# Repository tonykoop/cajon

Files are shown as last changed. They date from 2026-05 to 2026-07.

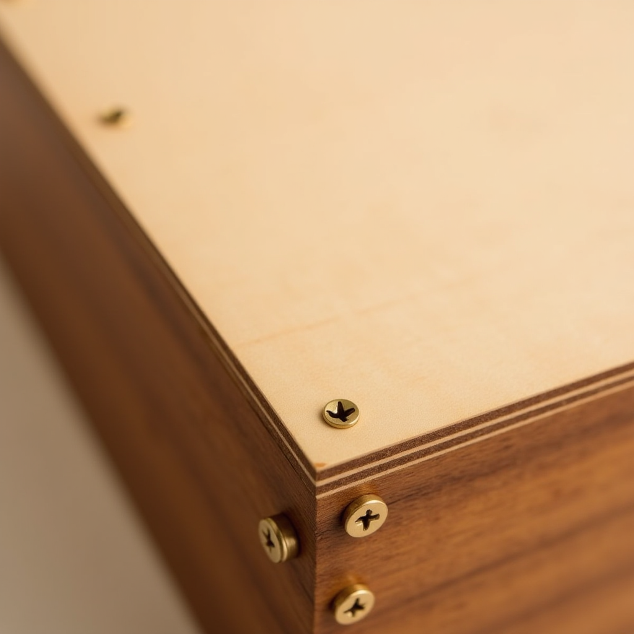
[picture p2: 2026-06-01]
images/macro/tapa-slap-zone.png

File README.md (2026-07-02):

# Cajón — Family Design Packet

**Status:** L2 V5 build-packet candidate — pre-build (not a measured or production-ready release yet; see "Current status" below).

**A parametric three-member box-drum family.** The Peruvian / flamenco cajón as a coordinated set of three sizes (Compact / Standard / Bass) in four interchangeable manufacturing variants, with an optional snare lineage.

Part of the [tonykoop/instrument-maker](https://github.com/tonykoop/instrument-maker) catalogue. Heifer Zephyr Instruments — Tony Koop.

---

## What this is

A complete parametric design packet for a coordinated three-member cajón family. The same design sheet drives all three sizes with a shared geometric law; the same shell can be realized through any of four joinery paths and either of three snare options.

| Member | Outer (H × W × D) | Sound hole | Predicted f_H | Voice |
|---|---|---|---|---|
| Compact (CJ-C)| 15 × 11 × 11 in | 4.0 in Ø | ≈ 107 Hz | bright G♯2/A2 |
| **Standard (CJ-S)** ⭐ | 18 × 12 × 12 in | 4.5 in Ø | ≈ 96 Hz | balanced G2 — first prototype |
| Bass (CJ-B) | 22 × 14 × 14 in | 5.0 in Ø | ≈ 77 Hz | deep D♯2/E2 |

| ID  | Joint | Method | Notes |
|-----|---|---|---|
| V1 ⭐ | Finger / box joint | Table saw + jig OR CNC parametric | First-prototype default |
| V2  | Half-blind dovetail| CNC | Showpiece, harder fixturing |
| V3  | Rabbet | Table saw or router | Quick commercial baseline |
| V4  | Miter + spline | Table saw + spline jig | Spline visual ties to inlay |

| Snare  | Lineage | Voice |
|---|---|---|
| A | Peruvian  | dry, woody, deep "thump" |
| B ⭐ | Flamenco  | bright, snappy slap; modern default |
| C | Studio | thicker buzz from snare-drum wires |

The packet ships acoustic physics, parametric geometry, BOM &middot; sourcing &middot; cut-list &middot; validation, dimensioned drawings, an assembly manual covering all four variants, a red-team risks log, a Wolfram starter notebook, a capstone slide deck, a printable shop packet, and a public build-log site.

## Current authority status

Current status: **pre-build V5 build-packet candidate**. The packet has a
design table, OpenSCAD master, SVG review drawings, CNC/jig notes, print packet,
capstone deck, and explorer, but it is not a measured or production-ready
release yet.

**Blender render scaffolding in place** (Refs #4): `cad/mcp-session-log.md`,
`visual-output-register.csv` render rows, and `images/render-brief.md` are
committed. Actual PNG renders remain `pending_measurement` until a Blender
MCP session runs via Claude Desktop and updates the session log.

Fabrication authority is limited to the named design table, OpenSCAD source,
fixture templates, and reviewed drawing set listed in
`visual-output-register.csv`. Snare response, panel-thickness behavior, joinery
strength, and strike-response claims remain predictions until the Standard
`CJ-S` prototype is built and `validation.csv` contains measured rows.

---

## Governing physics

The cajón's bass voice is the coupling of two systems within a few semitones of each other:

- **Front-plate (1,1) clamped-rectangular bending mode** — the 3 mm Baltic-birch tapa, clamped on all four edges by perimeter screws every 3″, vibrating in a single hump when struck centre.
- **Helmholtz cavity** — the closed walnut box with a 4.5″ back-port hole.

Standard prediction: plate (1,1) ≈ **84 Hz**; cavity ≈ **96 Hz**; perceived bass is the coupled mode of both. Strike centre → bass voice. Strike upper corner → slap zone bends and excites high modes + the snare.

```
f_H = (c / 2π) · √( A / (V · L_eff) )
       L_eff = t_back + 1.7 · (d_hole / 2)
```

The original `cajon-design-table.xlsx` formula used `L_eff = t_back` — missing the 1.7·r end correction. That under-predicted L by ~5–10× and over-predicted f_H by ~3×. Risk **A2** in `risks.md` tracks the correction; `design.md` uses the corrected expression; `cajon-design-table.xlsx` formula update is queued for v2.

For the full derivation, family scaling law, and assumptions, see [`design.md`](design.md).

---

## First prototype

> Build the Standard (CJ-S) in V1 finger-joint with snare option B. Standard is the family's tonal centre; Compact and Bass scale geometrically once Standard's measured tuning lands.

- Estimated material cost: **~$205** (one Standard prototype)
- Estimated build time: **~30 hours over 4 days** with CNC for inlay + joinery
- Default body species: Black walnut · CNC-inlaid sides with maple + yellowheart accents

---

## File map

| File / folder | Purpose |
|---|---|
| [`design.md`](design.md) | Governing physics, family scaling, critical dims, open assumptions |
| [`family-spec.csv`](family-spec.csv) | Three-member sizing law for Compact / Standard / Bass |
| [`cajon-design-table.xlsx`](cajon-design-table.xlsx) | Artisan-style reference workbook (in repo) |
| [`bom.csv`](bom.csv) | Bill of materials, by variant |
| [`sourcing.csv`](sourcing.csv) | Suppliers, lead times, price-volatility flags |
| [`cut-list.csv`](cut-list.csv) | Operation-by-operation cut data |
| [`validation.csv`](validation.csv) | Predicted vs measured tuning + acceptance bands |
| [`validation-report.md`](validation-report.md) | Pre-build validation status, gates, and release checklist |
| [`assembly-manual.md`](assembly-manual.md) | Phase-by-phase build (10 phases × 4 variants × 3 snare options) |
| [`supplier-rfq.md`](supplier-rfq.md) | Q2 2026 batch sourcing summary for prospective suppliers |
| [`drawing-brief.md`](drawing-brief.md) | List of required drawings + conventions |
| [`visual-bom-brief.md`](visual-bom-brief.md) | Visual-BOM photo brief |
| [`photo-shotlist.md`](photo-shotlist.md) | In-shop process photo list |
| [`resources.md`](resources.md) | Provenance, assumptions, and supplier verification notes |
| [`jig-decision.md`](jig-decision.md) | Fixture choices for square assembly, drilling, and repeatability |
| [`risks.md`](risks.md) | Red-team failure-mode walk (17 risks, 5 categories) |
| [`visual-output-register.csv`](visual-output-register.csv) | Visual/CAD authority chain for drawings, templates, generated previews, and image placeholders |
| [`wolfram-starter.wl`](wolfram-starter.wl) | Wolfram package: plate, Helmholtz, two-zone synthesis |
| [`capstone-deck.md`](capstone-deck.md) | Markdown capstone companion for validator and review |
| [`capstone-manifest.json`](capstone-manifest.json) | Capstone file map and public-release concerns |
| [`print-packet.md`](print-packet.md) | Printable shop packet in Markdown |
| [`print-packet.html`](print-packet.html) | Browser-printable shop packet |
| [`drawings/`](drawings/) | Dimensioned SVG drawings (sheets 1–8) |
| [`cad/`](cad/) | OpenSCAD parametric master (`cajon-master.scad`) |
| [`evolution/`](evolution/) | StudioPipeline Stage-0 intake (design intent, master manifest, revisions) |
| [`cnc/`](cnc/) | CNC bit + feed strategies for finger-joint, inlay, sound hole |
| [`jigs/`](jigs/) | Fixture drawings for square assembly and tapa screw layout |
| [`images/`](images/) | Concept/support image placeholders; future real build photos only after prototype evidence exists |
| [`data/`](data/) | Measurement-log landing zone for first-build spectral, load, and fit data |
| [`site/index.html`](site/index.html) | Public build-log site |
| [`scripts/`](scripts/) | Generators for xlsx, pptx, pdf binaries |
| [`BUILD.md`](BUILD.md) | How to regenerate the binary deliverables |
| [`LICENSE`](LICENSE) | CC BY 4.0 |

Generated binaries (run `python scripts/build_all.py`):

- `Cajon-Family-Design.xlsx` — parametric workbook ingesting the CSVs
- `Cajon-Family-Capstone.pptx` — capstone slide deck
- `Cajon-Family-Print-Packet.pdf` — printable shop packet
- `capstone-deck.pptx` and `print-packet.pdf` — validator-compatible root-mode aliases

---

## What's parametric vs measured

| Parametric (formula-driven, edit the workbook to change) | Measured (TBD on first prototype) |
|---|---|
| Helmholtz frequency f_H per member | Actual f_H of the assembled cavity |
| Plate (1,1) mode estimate per member | Actual plate (1,1) of mounted tapa |
| Internal cavity volume | Slap-vs-centre spectral delta |
| Sound-hole area + L_eff | Snare-buzz onset velocity (subjective) |
| Family table dimensions | Sustain T60 of the bass voice |
| Joint / bit / feed parameters | Tapa screw-torque uniformity |

---

## Status &amp; roadmap

- **Design v1 — shipped as pre-build V5 candidate.** Governing physics, family scaling, BOM/sourcing/cut-list/validation, drawings, CAD master, CNC notes, jigs, risks, Wolfram starter, build-log site, build scripts, explorer, and authority register.
- **First prototype build — pending.** Standard (CJ-S), V1 finger-joint, snare option B.
- **Tuning calibration — pending first measurement.** Once recorded, the family scaling law gets cross-checked against the data per the empirical-learning loop in the parent `instrument-maker` skill.
- **Drawings v2 — queued.** Current sheets 01–08 are public-review SVGs; next pass should replace simplified sheets with CAD-exported dimension drawings after the first build review.
- **Workbook formula revision — queued.** Replace `L = t_back` with `L_eff = t_back + 1.7·r` in `cajon-design-table.xlsx`.

## Review Evidence

- `git diff --check` is expected to pass for the packet branch.
- `python3 /home/tony/.codex/skills/instrument-maker-v4/scripts/validate_packet.py . --mode root`
  is the root-mode gate before merge review.
- This packet is a pre-build V5 candidate: design, sourcing, cut list,
  drawings, CNC notes, jigs, risks, validation plan, print packet, capstone,
  explorer, and visual authority register are present for human review.
- Empirical/build gates remain deferred until the Standard CJ-S prototype is
  assembled, measured, and logged in `validation.csv`.

---

## License

[CC BY 4.0](LICENSE) — see LICENSE for details.

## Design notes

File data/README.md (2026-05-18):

# Cajon Measurement Data

This folder is the landing zone for measured CJ-S prototype data.

Do not promote the packet beyond pre-build V5 candidate status until measured
rows exist in `../validation.csv` and source files are added here for the
critical gates:

- panel thickness after milling and after inlay routing;
- finger-joint scrap-fit and glue-line checks;
- shell diagonal/squareness and seat-load results;
- centre-strike and corner-strike audio captures or spectrum summaries;
- snare-onset notes for option B guitar-string snare;
- finish and tapa screw-torque observations.

Suggested file names:

- `cj-s-panel-thickness.csv`
- `cj-s-shell-squareness.csv`
- `cj-s-strike-spectrum.csv`
- `cj-s-snare-onset.md`

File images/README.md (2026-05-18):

# Cajon Images

This folder is reserved for real CJ-S build photos, validated renders, and
future concept/support imagery.

Generated images and site previews are concept/support only. They must not be
used to infer panel thickness, snare contact geometry, screw positions, joinery
tolerances, or CNC toolpaths. Record any accepted visual artifact in
`../visual-output-register.csv` before referencing it from the README, explorer,
site, print packet, or capstone deck.

Recommended future evidence:

- `cj-s-hero.jpg` after the first real prototype is built.
- `snare-contact-closeup.jpg` after snare preload is set.
- `tapa-screw-pattern.jpg` after the tapa is mounted.
- `validation-setup.jpg` showing tap-test or spectrum capture setup.

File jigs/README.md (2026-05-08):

# Cajon Jigs

The cajon looks like a cabinet until the tapa goes on. These jigs keep it an instrument.

## Required for CJ-S first prototype

1. **Square assembly fixture** - flat baseboard with fixed 90-degree fences and movable clamp blocks. Use during dry fit and glue-up.
2. **Tapa screw template** - hardboard or acrylic drill template indexed from the bottom outside edge and centerline. This protects the screw spacing and the unscrewed slap-zone margin.
3. **Back-panel template** - sound-hole center, tuner holes, and snare mount pilot layout. This can be combined with the tapa template if made from clear acrylic.

## Optional variant jigs

- **Finger-joint sled** for a table-saw V1 build.
- **Spline sled** for V4 miter+spline corners.
- **CNC dovetail fixture** for V2 half-blind dovetails.

## Build order

Make the square assembly fixture and screw template before cutting final tapa stock. The templates should be tested on scrap with the exact screws and tuner hardware from `bom.csv`.

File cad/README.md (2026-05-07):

# CAD — Cajón Family

This folder is the home for SolidWorks parametric models, OpenSCAD masters, and CAD-export geometry that drives the manufacturing files in `cnc/` and the dimensioned drawings in `drawings/`.

## Status

The cajón is a six-panel rectilinear box, simpler than a turned-shell instrument like the conga or udu. CAD complexity sits in the joinery (finger / dovetail / spline) and the inlay zone, not in the body geometry. As of v1:

- **`cajon-master.scad`** — OpenSCAD parametric master for the box body, sound hole, and finger-joint corners. Edit the parameters at the top, render, and export STL/DXF.
- **SolidWorks model** — *queued for v2*. Standard SW workflow per `instrument-maker-v4/references/solidworks-integration.md`: MasterLayout part + design table linked to `cajon-design-table.xlsx`. The OpenSCAD model is sufficient for v1 cut-list verification.

## Workflow

1. Edit the OpenSCAD master parameters to match the family member you want (Compact / Standard / Bass).
2. Render in OpenSCAD; export DXF (top view) for laser-cutting flat panels OR STL (full body) for visualization.
3. Cross-check OpenSCAD geometry against `cajon-design-table.xlsx` outputs; numbers must agree.

## Files

| File | Purpose |
|---|---|
| `cajon-master.scad` | OpenSCAD parametric body — edit + render |
| (planned) `cajon-master.sldprt` | SolidWorks part with design table |
| (planned) `cajon-assembly.sldasm` | SolidWorks assembly: 6 panels + glue blocks |
| (planned) `cajon-drawing.slddrw` | SolidWorks drawing → exports the SVGs in `../drawings/` |

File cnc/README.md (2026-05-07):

# CNC — Cajón Family

CNC strategy notes for the three operations on the cajón that benefit from CNC vs hand-tool execution: **(1)** finger-joint corners, **(2)** inlay pockets and inserts, **(3)** the back-panel sound hole.

The cajón is otherwise table-saw / router / hand-tool friendly. There is no complex profile-turning or coupling like the conga or fujara — the box is rectilinear.

## Machine + tooling assumptions

- Router: ShopBot Desktop or equivalent (24″ × 36″ work envelope minimum)
- Spindle: 2.2 kW, variable 6,000–24,000 RPM
- Bits used:
  - **TBN-12.4** — Amana 45739, 12.4° tapered ball-nose, 1/4″ shank — for inlay pocket + insert
  - **SF-1/2** — Amana 46176, 1/2″ straight-flute spiral, 1/4″ shank — for finger joint
  - **DT-14** — Amana 45813, 14° dovetail, 1/2″ — for V2 dovetail (optional)
  - **HSAW-4.5** — 4.5″ hole-saw (alternative to CNC pocket for sound hole)
- Vacuum hold-down preferred for inlay panels; T-track clamps acceptable for joinery.

## Operation 1 — Finger-joint corners (V1)

The 1/2″ spiral bit cuts 0.375″-wide finger pockets. Standard pin spacing is 0.375″; for a 12″ panel that's 32 fingers — even number, alternating pins, mating panels offset by one pin width.

```
Bit:        SF-1/2 (1/2" straight-flute spiral)
Feed:       40 IPM
Plunge:     12 IPM
RPM:        16,000
Step-down:  0.25" per pass (max)
Tool path:  pocket toolpath, ramp entry
```

**Critical:** verify kerf and spiral direction with a test cut on scrap. A down-cut spiral leaves a cleaner top edge but loads chips downward; an up-cut clears chips but tear-outs the top edge of walnut. Compromise: compression bit if you have it; up-cut + skim pass at 0.005″ depth as a finish pass otherwise.

The finger pattern is **mirrored on mating panels** — left side of side panel mates with left side of top panel; the pocket on one is the pin on the other. Generate the mating G-code from the same VCarve project, just toggle the layer.

## Operation 2 — Inlay pocket + insert (Broinwood-derived)

This is the high-leverage CNC operation on the cajón. It's the visual signature.

```
Bit:        TBN-12.4 (12.4° tapered ball-nose)
Feed:       30 IPM
Plunge:     10 IPM
RPM:        18,000
Pocket depth:    0.080–0.100" (pocket = negative, in walnut)
Insert depth:    pocket_depth + 0.020" (positive, in maple)
Tool path:  follow-vector for insert; pocket-clearance for pocket
```

The bit's tapered profile creates undercut walls in the pocket and matching tapered shoulders on the insert. As the insert is pressed in, the tapered shoulder seats against the tapered pocket wall — no glue gaps visible from the top once flush-sanded.

**VCarve allowance setting:** start at 0.000″ (factory default). If dry-fit is too tight (insert won't seat with thumb pressure), increase by 0.005″. If dry-fit is loose (rocks in pocket), decrease by 0.005″. *Always test on scrap before committing to the panel.*

**Panel keep-out:** route only within the central 70 % of the panel — keep 1″ clear of every joint edge so the joinery has solid wood.

## Operation 3 — Sound hole

Two acceptable paths:

**A. CNC pocket (preferred)** — cleanest result, no rasping required.
```
Bit:        SF-1/2 (1/2" straight-flute spiral)
Feed:       30 IPM
Plunge:     8 IPM
RPM:        16,000
Step-down:  0.10" per pass
Tool path:  pocket-clearance, spiral-entry, full-through (back panel is 0.5")
```

**B. Hole saw + jigsaw + rasp** — works fine, more cleanup.
- 4.5″ hole saw on drill press, low RPM (~250)
- Or: drill 1/2″ pilot, jigsaw + circle jig
- Rasp + 220 grit deburr both sides

Either way: **deburr both sides 220 grit minimum.** A sharp inside edge on the sound hole creates audible high-frequency hash on slap strokes.

## Operation 4 — Half-blind dovetail (V2 optional)

```
Bit:        DT-14 (1/2" 14° dovetail)
Feed:       25 IPM
Plunge:     8 IPM (carefully — dovetail bits do not plunge well; ramp instead)
RPM:        14,000
Tool path:  Dovetail-specific (use VCarve's half-blind dovetail wizard)
```

Half-blind dovetails on a CNC need a precision fixture — the bit cuts pin and tail in two different orientations, and the panels must register identically. Use a sled fixture or Whiteside-style dovetail jig with CNC-mounted bits if available.

## File outputs (planned, not yet generated)

- `cajon-fingerjoint-side.nc` — G-code for finger-joint side panel pockets
- `cajon-fingerjoint-top.nc` — G-code for top/bottom panel mating fingers
- `cajon-inlay-pocket.nc` — pocket toolpath for inlay pattern (panel-A example)
- `cajon-inlay-insert.nc` — insert toolpath for matching inlay
- `cajon-soundhole.nc` — pocket toolpath for back-panel sound hole

Generate these from VCarve Pro projects pulling geometry from `cajon-master.scad` (export DXF) and the inlay artwork SVGs (Broinwood-style geometric patterns or custom).

## Setup checklist

Before any CNC pass on a real panel:
- [ ] Spoilboard surfaced flat within 0.005″
- [ ] Vacuum or clamps verified (no movement under hand pressure)
- [ ] Bit depth-of-cut and shank engagement checked
- [ ] X/Y/Z zero set to a permanent reference (not the corner of the workpiece)
- [ ] Test cut on identical-thickness scrap at the same fixture position
- [ ] Dust collection on, ear protection on
- [ ] First 10 % of toolpath observed before walking away

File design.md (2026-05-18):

# Cajón Family — Parametric Design Sheet

**Owner:** Tony Koop · Heifer Zephyr Instruments
**Family:** Box drum, six-sided closed box, single thin front plate (tapa), back-port Helmholtz, optional internal snare
**Members:** Compact (CJ-C), Standard (CJ-S, prototype), Bass (CJ-B) — coordinated three-size family
**Manufacturing variants:** four end-to-end paths (V1 finger-joint / V2 dovetail / V3 rabbet / V4 miter+spline) — each with a snare/no-snare option
**Status:** Design v1 — workbook formulas parametric; family tuning predictions populated; first prototype is Standard with finger-joint shell + guitar-string snare; tuning calibration pending first measurement.

---

## Authority boundary

This packet is a pre-build V5 build-packet candidate. The design table,
OpenSCAD master, jig templates, and reviewed SVG sheets are the current planning
authority. They are not a substitute for measured panel stock, CNC test cuts,
seat-load tests, strike-response captures, or snare-onset measurements.

Generated previews, site imagery, visual-BOM layouts, and future concept images
are support artifacts only. The packet records visual and CAD authority in
`visual-output-register.csv`; no image or preview should be used to infer panel
thickness, snare contact geometry, screw positions, joinery tolerances, or CNC
toolpaths.

## 1. Intent

Document the cajón as a portfolio-grade parametric instrument, not as one box. The same design sheet drives three sizes (Compact / Standard / Bass) with a single shared geometric law, and the same shell can be realized through four joinery paths and either lineage of snare:

| Lineage | Snare | Character |
|---|---|---|
| Peruvian  | None (or finger-mute pad) | Dry, woody, deep "thump"; tonal pitch reads cleanly |
| Flamenco  | Guitar strings (adjustable) | Bright, snappy slap on edges; modern default |

A fifth artifact — the existing CNC inlay workflow (Broinwood-derived) — is the visual signature: walnut body with maple/yellowheart inlay panels, with the inlay routed before assembly so the pockets are clamped flat.

The cajón's "secret" is that two simultaneous resonators tune together: the Helmholtz cavity (`f_H`) sits within a few semitones of the tapa (1,1) plate mode, and the player perceives the *coupled* note as the bass voice. Designing the family is therefore a matter of co-tuning those two systems while keeping snare-buzz, slap-zone geometry, and seat-height ergonomics inside their own envelopes.

---

## 2. Family scaling law

The cajón family is a *closed-box, single-thin-plate, back-ported Helmholtz* drum. Two governing modes are co-dominant in the bass voice: the front-plate (1,1) bending mode and the cavity Helmholtz mode. Both must be modeled; the perceived bass pitch is the lower of the two if they are well separated, or a coupled hybrid if they are within ~6 semitones.

### 2.1 Tapa front plate — clamped rectangular plate, (1,1) mode

For an orthotropic plywood plate clamped on all four edges (the cajón seats the tapa under screws every ~3″ around the perimeter; the central span is the active region), the (1,1) bending-mode fundamental is approximated by the isotropic clamped-plate expression:

```
f_plate_(1,1) ≈ (π / 2) · (1/a² + 1/b²) · √( D / (ρ · h) )
```

where `a, b` are the clear span (in metres), `h` is plate thickness, `ρ` is panel density, and `D = E·h³ / (12·(1−ν²))` is flexural rigidity.

For a 3 mm Baltic-birch tapa (`E ≈ 8 GPa`, `ρ ≈ 680 kg/m³`, `ν ≈ 0.30`), this places the (1,1) mode in the 60–110 Hz band over the family — which is exactly where you want it for "thump on the centre, snap on the edge."

### 2.2 Cavity — Helmholtz back-port

For the box cavity coupled to a circular back-port:

```
f_H = (c / 2π) · √( A / (V · L_eff) )
       L_eff = t_back + 1.7 · (d_hole / 2)
```

where `V` is internal volume, `A = π·(d/2)²` is the port area, `t_back` is back-panel thickness, and `1.7·r` is the standard end-correction for a thin-wall flush orifice (both sides counted).

The original spreadsheet (`cajon-design-table.xlsx`) used `L_eff = t_back` only. That under-predicts L by ~5–10× for typical cajón dimensions and over-predicts `f_H` by a factor of ~3. The corrected formula is what the workbook uses now; the historical predictions are flagged in `risks.md` as **A4**.

### 2.3 Family scaling

Volume scales roughly with H·W·D, so `f_H ∝ 1/√V` for a constant port. To keep `f_H` proportional to a target pitch span across the family, the port diameter is also scaled — larger box ⇒ larger port to push `f_H` back up; smaller box ⇒ smaller port. The catalog defaults below split the family into a P1 / P2 / P3 voice each separated by ~3–4 semitones.

| Member | H (in) | W (in) | D (in) | Body t (in) | Back t (in) | Port d (in) | Tapa t (mm) | Predicted f_H (Hz) | Predicted plate (1,1) (Hz) | Tonal voice |
|---|---|---|---|---|---|---|---|---|---|---|
| Compact (CJ-C)| 15 | 11 | 11 | 0.625 | 0.50 | 4.0 | 3 | 107 | 107 | bright A2/G♯2 |
| **Standard (CJ-S) ⭐** | 18 | 12 | 12 | 0.75 | 0.50 | 4.5 | 3 | **96** | **84** | balanced G2 |
| Bass (CJ-B) | 22 | 14 | 14 | 0.75 | 0.50 | 5.0 | 3 | 77 | 60 | deep D♯2/E2 |

All values from the parametric design sheet; the workbook is the source of truth for any update.

The Compact accidentally lands with `f_H ≈ f_plate` — that's the "tightly coupled" regime and produces the punchiest, most pitch-distinct bass in the family. The Bass deliberately separates them by ~5 semitones so the cavity rumble dominates; the plate then acts mainly as the slap voice.

---

## 3. Snare strategy

The cajón has three valid snare paths. The workbook supports all three; the first prototype runs **option B**:

| ID | Snare | Mechanism | Use |
|----|---|---|---|
| A  | None (Peruvian) | bare cavity; finger pad or palm mute on outside if a softer, more melodic voice is wanted | trad / world percussion |
| B  | Guitar-string snare ⭐ | 3–4 wound or plain steel guitar strings clamped on an angled internal block; tension adjustable via guitar tuners | flamenco / modern default |
| C  | Snare-drum wires | a section of standard snare-drum wires mounted on a tension lever; thicker buzz, less articulate | studio / loud genres |

Snare wires sit *behind* the tapa, lightly contacting the inside face. The contact force is the tunable: too light = no buzz; too heavy = chokes the slap and overhangs the bass.

---

## 4. Joinery / construction variants

The shell is a six-sided box. Five of the six faces (top, bottom, two sides, back) are 3/4″ Black Walnut by default; the sixth face is the 3 mm Baltic birch tapa. The four major joinery paths each ship as a manufacturable option:

| ID | Joint | Method | Strength | Visual | Difficulty | Notes |
|----|---|---|---|---|---|---|
| V1 | Finger / box joint ⭐  | table saw + jig OR CNC parametric | ★★★ | ★★★ — contrasting maple fingers possible | medium | First-prototype default; CNC route enables variable-width fingers |
| V2 | Half-blind dovetail | CNC | ★★★ | ★★★ — heirloom | hard | Showpiece path; needs jig fixtures + dust collection |
| V3 | Rabbet | table saw or router | ★★ | ★ — hidden | easy | Commercial baseline; quickest to build |
| V4 | Miter + spline | table saw + spline jig | ★★★ | ★★★ — contrasting splines visible | medium | Clean show-up corners; spline inlay ties to the inlay aesthetic |

V1 (finger joint) is the recommended first prototype: it tolerates ±0.005″ panel error gracefully, the jig is reusable, and the visible joint complements the inlay.

The tolerance claim is a design target, not a measured result. Validate it with
scrap finger-joint samples and the square assembly jig before cutting show
stock.

---

## 5. CNC inlay strategy

The cajón's six flat faces are a perfect canvas for the Broinwood-style ball-nose inlay technique. Critical rule: **route inlay before assembly.** Once the box is glued, you cannot clamp panels flat for routing.

The workflow ships in detail on `cajon-design-table.xlsx` § "CNC Inlay Workflow". Summary:

1. Two paired toolpaths per inlay element: a *pocket* (negative) cut into the body panel and an *insert* (positive) cut from contrasting wood. Both use the same TBN 12.4° tapered-ball-nose bit.
2. Pocket depth 0.080–0.100″; feed 30 IPM at 18,000 RPM in walnut. Test-cut on scrap to dial allowance.
3. The inlay-allowance setting in VCarve Pro controls press-fit. Too tight cracks the insert; too loose leaves a visible gap line.
4. Glue with Titebond III, clamp flat with wax-paper underlay, cure 24 hours, then drum-sand the panel flush before joinery.

Visual layout default for the prototype:
- **Side panels (2):** geometric mandala or Celtic-knot pattern, ~70% of panel area
- **Back panel:** rosette around the sound hole only
- **Top (seat):** subtle border inlay; nothing raised (you sit on it)
- **Tapa:** no inlay (active surface, you hit it; preserve plate uniformity)

---

## 6. Critical dimensions (Standard, V1 finger-joint, snare option B)

These are the numbers that drive cut-list, drawings, and CNC. Anything not here is either derived in the workbook or a non-critical aesthetic choice.

| Feature | Dimension | Tolerance | Source |
|---|---|---|---|
| Outer height | 18.000″ | ±0.020″ | family table |
| Outer width | 12.000″ | ±0.020″ | family table |
| Outer depth | 12.000″ | ±0.020″ | family table |
| Body panel thickness | 0.750″ | ±0.005″ | stock spec |
| Tapa thickness | 0.118″ (3 mm) | +0/−0.005″ | Baltic birch ply spec |
| Back panel thickness | 0.500″ | ±0.005″ | stock spec |
| Sound-hole diameter | 4.500″ | ±0.020″ | family table |
| Sound-hole position | centred L–R, 1/3 H from top on back panel | ±0.10″ | trad practice |
| Tapa screw spacing | every 3″ | ±0.10″ | trad practice |
| Slap-zone unscrewed margin | top 4–5″ of tapa, both upper corners | as drawn | trad practice |
| Internal corner glue blocks | 8× ¾″ triangle, full panel height | hand-fit | rigidity / overtone control |
| Snare angle (option B) | 8–12° off vertical, contact 1″ below top | ±2° | trad practice |
| Rubber-foot height | 0.50″ | ±0.05″ | airflow + bass projection |

Datums for drawings: bottom outside face = primary horizontal datum (Z = 0); back outside face = secondary; centerline of tapa width = vertical reference.

---

## 7. What's parametric vs. what's measured

**Parametric (formula-driven, edit the workbook to change):**
- Helmholtz frequency `f_H` per member
- Plate (1,1) mode estimate per member
- Internal cavity volume
- Sound-hole area and effective neck length
- Family table member dimensions
- Joint / bit / feed parameter recommendations

**Measured (TBD on first prototype, will populate `validation.csv`):**
- Actual `f_H` of the assembled cavity (tap-and-record, expect ±10 Hz from prediction)
- Actual plate (1,1) of the mounted tapa (varies with screw torque and tapa moisture)
- Slap-zone vs centre-strike spectrum delta (`risks.md` E1 acceptance test)
- Snare-buzz onset velocity (subjective; recorded per snare option)
- Sustain T60 of the bass voice
- Actual panel thickness after milling, tapa thickness after finish, and any
  local thinning from CNC inlay pockets
- Finger-joint fit, glue-line closure, diagonal squareness, and seat-load
  behavior

A second-pass design sheet revision happens after the first prototype is measured. The empirical correction (`f_H_predicted` vs `f_H_measured`) gets logged in `validation.csv`, and any cents-error >50 cents triggers a family-table revisit.

---

## 8. Open assumptions

These are explicit so the reviewer knows what is *concept* vs *manufacturable*:

1. **Tapa material is treated as isotropic.** Real Baltic birch ply is mildly orthotropic; the (1,1) prediction is a coarse estimate — expect ±20% from the simple formula. A measured tapa will be the source of truth.
2. **Snare contact pressure is not yet a parameter** in the workbook. It is dialed by ear on the first prototype.
3. **Glue-block contribution to plate clamping is unmodeled.** The 8 internal glue blocks effectively change the plate boundary condition near the corners; we treat the full panel as clamped, which over-stiffens the model slightly.
4. **CNC inlay pocket depth has not been verified to leave structural panel above the pocket.** 0.080″ pocket in 0.625″ stock leaves 0.545″ — comfortably safe — but is recorded as a check in `risks.md` (S2).
5. **Panel material defaulted to Black Walnut** for the visual contrast story; the workbook supports any species but the BOM and cost numbers assume walnut.

---

## 9. First-prototype recommendation

Build the **Standard (CJ-S), V1 finger-joint, snare option B** as the first instrument. Reasons:

- Standard is the family's tonal centre; if its measured tuning lands on prediction, the Compact and Bass scale by simple geometry from there.
- V1 finger-joint is forgiving on stock-prep error and uses the same CNC fixture as future variants.
- Snare option B (guitar strings) is the modern default; the snare can be removed or detensioned to demo "Peruvian style" without rebuilding the box.

Total estimated material cost for prototype: ~$200 (see `bom.csv`). Estimated build time, in-shop, with CNC for joinery and inlay: ~30 hours over 4 days (acclimate / mill / inlay / joinery / glue-up / sand / finish / mount / tune).

---

## 10. References

- `cajon-design-table.xlsx` — workbook source of truth (all formulas live)
- `bom.csv` — bill of materials, all variants
- `sourcing.csv` — suppliers, lead times, price-volatility flags
- `cut-list.csv` — operation-by-operation lumber and stock cuts
- `validation.csv` — predicted vs measured tuning + acceptance bands
- `assembly-manual.md` — phase-by-phase build procedure
- `risks.md` — red-team acoustic / structural / ergonomic / supply / fit-finish failure modes
- `wolfram-starter.wl` — Wolfram package: plate, Helmholtz, two-zone synthesis
- `drawing-brief.md` — list of required drawings + conventions
- `drawings/*.svg` — dimensioned drawings
- `cad/` — SolidWorks placeholders (master layout to follow)
- `cnc/` — CNC inlay and finger-joint cut strategy notes
- `site/index.html` — public build-log site

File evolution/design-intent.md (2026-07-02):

# Design Intent — cajon rev A

- Master CAD: `cad/cajon-master.scad` (sha256: c33970154a3aaa114a9b48958d318e404c76e641e9f412e323f79ac2b02813f1), driven by `Cajon-Family-Design.xlsx` (sha256: d51e6aaaaa010b24bf17f511e03ac4ad37278c9b550844330ec9c4292a9f9eab) and `family-spec.csv`.
- Function: Parametric three-member box-drum family (Compact / Standard / Bass) in four manufacturing variants. A thin plywood front plate (tapa) is struck; its plate (1,1) mode couples with a Helmholtz cavity resonance through a back sound hole to produce bass and slap zones. CJ-S Standard is the first public-review prototype.
- Environment: seated hand-played acoustic box drum; plywood plates move with humidity (tapa stiffness ∝ h³); tapa is screwed (field-replaceable), body panels glued.
- Target qty: 1 (CJ-S Standard prototype first). Deadline: TBD. Budget/unit ceiling: TBD.

## Critical dimensions (carry tolerances)

| Feature | Nominal (CJ-S Standard) | Tolerance | Why critical | Source |
| --- | --- | --- | --- | --- |
| Outer HxWxD | 18.0 x 12.0 x 12.0 in | cut-list gate | seating / cavity volume | family-spec.csv CJ-S |
| Tapa thickness | 3.0 mm BB-grade birch | reject sheets >0.010 in off nominal | plate (1,1) ∝ h^3 → pitch | family-spec.csv / risks SU1 |
| Sound hole diameter | 4.5 in | affects f_H via effective length | Helmholtz tuning | family-spec.csv CJ-S |
| Predicted Helmholtz f_H | ~96 Hz (with 1.7·r end correction) | measure on prototype | bass voice | design.md / risks A2 |
| Predicted plate (1,1) | ~84 Hz | measure on prototype | slap/bass coupling | family-spec.csv CJ-S |
| Body / back thickness | 0.750 / 0.500 in | glue-joint squareness | structure | family-spec.csv CJ-S |

## Incidental (free for DFM)

- Finger-joint vs alternative corner variant, inlay/cosmetic detail, external finish, snare-option lineage (A/B), non-mating surface treatment.

## Must-nots (DFM may never violate)

- Do not use the original `cajon-design-table.xlsx` Helmholtz formula without the `1.7·r` end correction (L_eff = L + 1.7·r) — the uncorrected formula mispredicts f_H badly (risks A2).
- Do not spec non-BB / non-marine-grade ply; layer-adhesion and thickness variance (±8%) shift plate pitch ~15% (risks SU1, A1).
- Do not over-tighten the lower tapa screws — it tenses the slap zone at rest (risks mitigation).
- Do not treat family-spec predicted frequencies as measured — they are pre-build predictions pending CJ-S validation.

## Material intent

- Preferred: BB-grade / marine-grade Baltic birch plywood body and tapa per bom.csv; screwed replaceable tapa.
- Acceptable subs: per sourcing.csv (spec-first; price-volatility flags noted; live prices unverified).
- Forbidden: non-BB-grade plywood for the tapa.

## Stage status

Stage 0 intake complete 2026-07-01. Gate A (Alpha shop compile) NOT yet run — no concessions logged, nothing presented as shippable. Status normalized to L2 V5 build-packet candidate (pre-build; not measured/production-ready).

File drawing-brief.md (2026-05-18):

# Drawing Brief — Cajón Family

The `drawings/` folder ships dimensioned SVGs for the family. Each SVG follows Heifer Zephyr's standard title block (lower-right) with: drawing name, sheet number, scale, units, project (Cajón Family), date, revision, drafter (Tony Koop). All dimensions in inches unless noted.

Visual authority is tracked in `visual-output-register.csv`. The SVG sheets and
jig templates are review/manufacturing-planning artifacts derived from the
design table and OpenSCAD source; production CNC, panel-thickness, snare-contact,
and strike-response claims still require physical validation.

## Required drawings

| File | Sheet | Title | Notes |
|---|---|---|---|
| `01-family-front-elevation.svg` | 1/8 | Cajón Family — Front Elevation (C/S/B side-by-side)  | Tapa face dims, sound-hole position, scale  |
| `02-standard-isometric.svg` | 2/8 | Standard (CJ-S) — Exploded Isometric | Six-panel callout; tapa, back, sides, top, bottom + glue blocks |
| `03-back-panel-detail.svg` | 3/8 | Back Panel — Sound-Hole Position + Snare Mount | 4.5″ Ø hole, centred L–R, 1/3 H from top |
| `04-tapa-screw-pattern.svg` | 4/8 | Tapa Face — Screw Layout + Slap-Zone Margin | #6 brass every 3″; top 4–5″ unscrewed |
| `05-finger-joint-detail.svg` | 5/8 | V1 Finger Joint — Corner Section | 3/8″ pin spacing, parametric width |
| `06-dovetail-detail.svg` | 6/8 | V2 Half-Blind Dovetail — Corner Section | 14° pin angle, pin spacing |
| `07-snare-mount-detail.svg` | 7/8 | Snare Option B — Guitar-String Mount Block + Tuner | 8–12° angled face, contact 1″ below top |
| `08-cnc-inlay-zone.svg` | 8/8 | CNC Inlay Zone — Side Panel | 70 % active area, 1″ keep-out from edges |

## Drawing conventions

- **Datums**: bottom outside face = primary horizontal datum (Z = 0); back outside face = secondary; centerline of tapa width = vertical reference.
- **Tolerances**: ±0.020″ default; tighter where called out.
- **Cross-section hatching**: walnut grain at 45° for body wood; light cross-hatch at 90° for plywood (back + tapa).
- **Title block size**: 4″ × 1.5″ at 1:1 scale, lower-right corner.
- **Critical dimensions**: bold, with leader lines pointing to the dimensioned feature.
- **Material callouts**: keyed to `bom.csv` part_id where applicable.

## File status

All eight public-review SVG sheets ship in this root packet. Sheets 02, 06, 07, and 08 are intentionally simplified technical briefs rather than full CAD exports; they identify datums, critical features, fixture logic, and acceptance checks so a CAD operator can redraw them without guessing design intent.

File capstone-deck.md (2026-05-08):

# Title

Cajon Family Public-Review Prototype

Tony Koop / Heifer Zephyr Instruments. Root-mode packet for a three-member cajon family with a Standard first prototype.

# Project Intent

Turn a mechanically simple box drum into a repeatable, reviewable build. The contribution is not inventing the cajon; it is documenting a clean parametric family, robust joinery paths, explicit jigs, and measured tone/buzz validation so another maker can reproduce the work.

# Family Overview

Compact, Standard, and Bass members share the same layout law: rectangular shell, thin tapa, back sound hole, optional snare. Standard CJ-S is the first build because it sits in the ergonomic and tonal middle of the family.

# Governing Physics

The bass voice comes from a Helmholtz cavity coupled to the first bending mode of the tapa. The Standard target is 96 Hz cavity response and 84 Hz plate response, with the perceived bass expected near the coupled midpoint.

# Critical Geometry

The Standard prototype is 18 x 12 x 12 in with 3/4 in walnut body panels, 1/2 in back panel, 3 mm Baltic birch tapa, and a 4.5 in back sound hole. Tapa screw spacing and the unscrewed slap zone are treated as acoustic geometry.

# Joinery Strategy

V1 finger joint is the first public candidate because it is strong, teachable, and forgiving. V2 dovetail, V3 rabbet, and V4 miter+spline remain documented variants for later builds.

# Tapa and Screw Pattern

The tapa is mounted with #6 brass flathead screws roughly every 3 in. The upper 4-5 in corner zones are intentionally left loose so the corner strike can snap instead of choking.

# Snare Mechanism

Snare option B uses adjustable guitar strings contacting the inside of the tapa near the top. The design validates snare onset by feel and recording: no buzz on a light tap, clean buzz on a medium corner slap.

# Jig Plan

Three fixtures are required before the first build: a square assembly fixture, a tapa screw drilling template, and a back-panel drill template. These convert the simple box into a repeatable instrument rather than a one-off cabinet.

# BOM and Sourcing

The Standard prototype is estimated near 205 USD in materials and consumables. Supplier rows are representative; current prices, stock, and shipping terms must be rechecked before purchase.

# Cut List and Manufacturing Flow

Mill panels, route inlay before assembly, cut joinery, cut/deburr back sound hole, glue the shell square, mount the tapa, tension the snare, finish, and validate. The tapa is screwed, not glued, so it remains serviceable.

# Drawings, CAD, CNC

The repo includes SVG drawing sheets, an OpenSCAD master, CNC notes, and jig drawings. Public-review drawings emphasize datum chains, screw layout, sound-hole placement, and fixture-driven repeatability.

# Validation Plan

Validation measures shell squareness, seat load, sound-hole diameter, tapa torque uniformity, Helmholtz response, plate mode, coupled bass, slap spectral delta, snare onset, and finish feel. Results land in `validation.csv`.

# Risks

The main open risks are acoustic model drift from real plywood, non-uniform tapa screw torque, snare preload, supplier variation in 3 mm birch ply, and placeholder imagery before the prototype is photographed.

# Public Release Readiness

This is a fast public candidate after human build review. The packet is complete enough to invite critique, but the public page should clearly mark the design as pre-build until CJ-S measurements and real build photos exist.

# Next Actions

Build CJ-S V1 with snare B, record measured values, update the workbook formula if any stale Helmholtz cells remain, replace placeholder visuals with shop photos, and rerun the packet validator before release.

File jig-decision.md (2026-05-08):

# Jig Decision Log

This cajon is a simple box, so the jigs carry most of the repeatability. The public-review packet treats three fixtures as required for the Standard prototype and two as optional paths for later variants.

## Required jigs for the first prototype

| Jig | Decision | Why it is required | Acceptance check |
|---|---|---|---|
| Square assembly fixture | Build a flat baseboard with two fixed 90-degree fences, four movable clamp blocks, and diagonal check marks. | The shell has to glue square before the tapa can clamp evenly; a twisted box makes the tapa buzz unpredictably. | Dry-fit shell diagonals within 1/16 in before glue; after cure each face sits flat without rocking. |
| Tapa screw drilling template | Make a reusable 1/8 in hardboard or acrylic template indexed from the bottom and centerline. | The 3 in screw spacing and unscrewed top slap zone are tonal features, not decoration. A hand-marked layout is too easy to drift. | Holes land within +/-0.10 in of pattern; top 4.5 in corner slap zone remains undrilled. |
| Back-panel drill template | Make a template with the sound-hole center, tuner holes, and snare-mount pilot locations. | The sound-hole position sets the Helmholtz path and the tuner holes must align with the snare block. | Sound hole center within +/-0.10 in; tuner holes align without string rub. |

## Optional / variant jigs

| Jig | Use when | Decision |
|---|---|---|
| Finger-joint indexing sled | V1 table-saw build without CNC | Recommended if CNC is not used. Use a measured key equal to the actual dado kerf, not nominal cutter size. |
| Spline sled | V4 miter+spline showpiece | Required for V4. Three repeatable slots per corner are a visual commitment; freehand routing is not acceptable. |
| Dovetail vacuum fixture | V2 CNC half-blind dovetail | Required for V2. Treat as a separate CAM setup with sacrificial spoilboard and hold-down tabs. |

## Public-review decision

The first public candidate should ship as **CJ-S / V1 / snare B** with the square assembly fixture, tapa screw template, and back-panel template built before any final stock is cut. That keeps the prototype teachable: reviewers can evaluate tone and ergonomics without confusing fixture error for design error.

## Jig files in this repo

- `jigs/README.md` - fixture overview and build order.
- `jigs/tapa-screw-template.svg` - drill-template concept for the Standard tapa.
- `jigs/square-assembly-fixture.svg` - baseboard and clamp-block layout.

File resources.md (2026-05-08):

# Resources and Provenance

This file separates stable design references from time-sensitive supplier information so a public reviewer can see what is engineering input, what is shop preference, and what still needs human verification before purchase.

## Local packet sources

| Source | Role in packet | Notes |
|---|---|---|
| `README.md` | Public overview and file map | Root-mode entry point for outside reviewers. |
| `design.md` | Governing design narrative | Corrected Helmholtz end correction is documented here. |
| `cajon-design-table.xlsx` | Minimal workbook seed | Contains the starting cajon design table; workbook formula revision remains a public-release concern. |
| `Cajon-Family-Design.xlsx` | Generated family workbook | Generated from repo CSVs by `scripts/build_xlsx.py`. |
| `bom.csv`, `sourcing.csv`, `cut-list.csv` | Manufacturing packet tables | Costs and lead times are estimates and must be rechecked before buying. |
| `validation.csv` | Test plan and measured-data landing zone | No physical build data is present yet. |

## Acoustic and construction assumptions

| Topic | Stable basis | Packet treatment |
|---|---|---|
| Cavity resonance | Helmholtz resonator with a circular back port and thin-wall end correction | `L_eff = t_back + 1.7*r`; measured cavity response must confirm. |
| Tapa mode | First-order clamped rectangular plate model | Treated as a coarse estimate because plywood is orthotropic. |
| Cajon slap behavior | Traditional loose upper-corner tapa zone | Top 4-5 in at the upper corners remains unscrewed. |
| Snare behavior | Contact preload between internal wires/strings and tapa | Dialed by ear; validation records onset as a 1-5 subjective scale. |
| Seating load | Static shop validation, not formal furniture certification | 250 lb for 1 hour with post-test inspection. |

## Supplier facts to recheck before purchase

The packet names representative suppliers so the BOM is buildable, but it does not freeze current inventory, price, or shipping terms. Before buying material for a public build, recheck:

- Baltic birch 3 mm and 1/2 in grade, thickness tolerance, sheet flatness, and shipping damage policy.
- Walnut board grade, moisture content, delivered thickness, and actual board-foot waste.
- Solid brass #6 x 3/4 in flathead screws; reject brass-plated steel substitutions.
- Guitar tuner hole diameter and string path geometry against the back-panel template.
- Finish VOC rules and curing conditions in the actual shop.

## Public attribution notes

- The cajon is a widely used Afro-Peruvian / flamenco box drum form. The packet should not imply invention of the cultural instrument.
- The novel contribution here is the reproducible public-review build packet: parametric family sizing, jig decisions, validation gates, and documentation discipline.
- The public site should use actual build photography once available. Placeholder hero blocks are acceptable only before the first prototype exists.

## Measurement tools

| Tool | Why it is listed |
|---|---|
| Calipers | Panel thickness, sound-hole diameter, screw-template verification. |
| Framing square and tape | Shell squareness and diagonal checks. |
| Torque screwdriver | Optional but useful for tapa screw uniformity. |
| REW or equivalent spectrum analyzer | Helmholtz, plate, slap-vs-bass spectral delta, T60. |
| Smartphone tuner | Quick shop check, not final evidence by itself. |

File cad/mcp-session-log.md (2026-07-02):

# CAD / MCP Session Log — Cajón Family

Records every external-tool or MCP session that produced or modified an artifact
in this packet. Required by the V5 build-packet standard before any artifact may
claim MCP provenance.

One row per session × artifact. Add a new row immediately after each session.
Do not back-fill or estimate session IDs.

---

## Session log

| session_id | tool | input_authority | outputs | role | authority_result | review_status | notes |
|---|---|---|---|---|---|---|---|
| pending-blender-hero | Blender MCP | cad/cajon-master.scad (OpenSCAD STL export) | images/hero-render.png | concept_render | pending_measurement | pending | Planned: 3/4 view, 2048×1536 sRGB, studio lighting. See images/render-brief.md for full spec. |
| pending-blender-explode | Blender MCP | cad/cajon-master.scad (OpenSCAD STL export) | images/assembly-explode.png | concept_render | pending_measurement | pending | Planned: panels offset along face normals, exploded assembly diagram frame. |
| pending-blender-material-birch | Blender MCP | cad/cajon-master.scad; images/blender-scene.blend | images/material-study/birch-ply.png | concept_render | pending_measurement | pending | Planned: birch ply material variant, same camera as hero render. |
| pending-blender-material-walnut | Blender MCP | cad/cajon-master.scad; images/blender-scene.blend | images/material-study/walnut.png | concept_render | pending_measurement | pending | Planned: walnut material variant. |
| pending-blender-material-mdf | Blender MCP | cad/cajon-master.scad; images/blender-scene.blend | images/material-study/painted-mdf.png | concept_render | pending_measurement | pending | Planned: painted MDF variant. |
| pending-blender-scene | Blender MCP | cad/cajon-master.scad | images/blender-scene.blend | tool_source | pending_measurement | pending | Planned: saved .blend scene with reproducible camera, lighting, material nodes. Required by issue #4 acceptance criteria. |

## Authority boundary

No Blender MCP session has executed yet. All rows above are planning placeholders.
The `pending_measurement` authority_result blocks any render from being promoted
to fabrication or derived_preview authority until a real session ID replaces the
`pending-*` placeholders and review_status advances to `self_checked` or better.

Blender MCP requires Claude Desktop. When a session runs:
1. Replace the `pending-*` session_id with the actual session timestamp or ID.
2. Set `authority_result` to `concept_only` (renders are not dimensional authority).
3. Set `review_status` to `self_checked`.
4. Update `visual-output-register.csv` rows to match.

| fable-v5-refresh-2026-07-01 | claude-code (Fable 5) | Cajon-Family-Design.xlsx | Cajon-Family-Design.xlsx, cajon-design-table.xlsx, data/README.md | packet_refresh | fabrication | self_checked | V5 refresh pass; tabular design-table + measurement-template data reviewed against family design. No dimension changes made. Provenance rows added to satisfy V5 fabrication-artifact logging (design tables + data measurement landing zone). |
| fable-v5-refresh-2026-07-01 | claude-code (Fable 5) + OpenSCAD CLI | Cajon-Family-Design.xlsx | cad/cajon-master.scad | cad_review | fabrication | self_checked | Existing OpenSCAD master kept (not rewritten). openscad render check: pass (Simple: yes, exit 0). |

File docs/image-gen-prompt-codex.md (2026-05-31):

# Cajon Image-Gen Prompts

Concept visualization only; not fabrication authority. Do not infer panel
thickness, screw positions, snare geometry, CNC toolpaths, or tuning from these
prompts.

## Hero Prompt

Photorealistic 3/4 product photograph of a finished Standard cajon prototype from a parametric three-member family: a black walnut box drum with precise finger-joint corners, a thin Baltic-birch tapa front plate, a circular rear sound hole hinted by angle, and subtle maple plus yellowheart CNC inlay panels on the sides and back. The instrument should look like a refined furniture-grade percussion object, with rubber feet, clean tapa screws around the perimeter, and a warm satin finish. Clean studio background, soft directional lighting, realistic seated scale from a cushion or hands nearby, 50mm lens, high detail, photorealistic.

## In-Context Prompt

Photorealistic scene of the cajon being played in a small studio or woodshop performance corner: a seated player strikes the center of the tapa for bass while the upper corners suggest flamenco snare slap, with the walnut body and side inlay visible. Include a tuner, guitar-string snare adjustment tool, and wood offcuts in the background. Natural light, believable seated posture, no stage smoke, intimate acoustic storytelling.

## Detail / Macro Prompt

Photorealistic macro close-up of the cajon's front upper corner: thin Baltic-birch tapa with evenly spaced screws, crisp finger-joint walnut corner, a glimpse of contrasting maple/yellowheart inlay on the side panel, and the subtle shadow where the tapa can vibrate. Show satin finish, real wood pores, screw heads, and clean joinery. High-detail macro, shallow depth of field.

## Negative / Avoid

No text, logos, watermarks, fake brand badges, impossible box joints, extra limbs, distorted hands, visible dimension callouts, or random snare wires outside the box.

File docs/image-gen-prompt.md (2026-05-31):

# Image-Gen Prompts

Concept image only; not fabrication authority. Do not include cut-ready dimensions, hole locations, or toolpaths.

## Hero Prompt

A finished Peruvian/flamenco cajón box drum standing upright on a clean neutral seamless studio backdrop, photographed at a 3/4 product-photography angle with a ~50mm lens. The instrument is an upright six-sided rectangular wooden box roughly the proportions of a tall stool — clearly sized to be sat on — built from rich black walnut with warm chocolate grain. Five faces are solid walnut joined at the front corners with a crisp visible finger/box joint, the alternating pins picked out in pale contrasting maple so the corner reads as a woven light-and-dark seam. The two visible side panels carry a recessed CNC-routed geometric inlay panel — a mandala/Celtic-knot motif in maple and yellowheart set flush into the walnut, covering most of the panel with a clean margin of bare wood around the edge. The thin pale front playing surface (the tapa) is a smooth uniform Baltic-birch face, lighter than the walnut body, attached around its perimeter with small evenly spaced brass screw heads that stop a few inches short of the top corners leaving a clean unscrewed slap zone. Satin oil-and-poly finish with a soft sheen reading the grain; the box rests on four small low rubber feet that lift it slightly off the surface. Soft directional studio light from camera-left, gentle falloff, high detail, photorealistic, no text labels.

## In-Context Prompt

The same walnut cajón staged in a warm woodworking shop, sitting on a plank floor near a workbench with hand tools softly blurred in the background, lit by natural window light raking across the maple-inlaid side panel and the brass screw line of the tapa. A seated player is implied — hands resting on the upper edge of the front tapa as if about to strike the slap zone at the top corner, one palm near the centre for the bass note. Shallow depth of field, environmental storytelling, warm tone, concept visualization only, no text.

## Detail Prompt

Macro close-up of one front corner of the cajón where the finger/box joint meets the inlaid side panel: alternating maple and walnut box-joint pins interlocking cleanly at the corner, beside the flush press-fit edge of a maple/yellowheart geometric inlay seated into the walnut with a hairline-tight glue line. Raking low-angle light to bring out the wood grain, the depth of the routed pocket transition, and the satin finish micro-sheen. Extremely high detail, shallow depth of field, no measurements, no text.

## Negative / Avoid

No text, logos, watermarks, or fake maker marks; no dimension callouts, leader lines, or measurements; no impossible joinery or floating parts; tapa screws must stop short of the top corners; anatomically plausible hands if a player is shown.

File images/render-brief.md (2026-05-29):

# Cajón Family — Blender MCP Render Brief

This brief specifies the complete render setup for issue #4 (Blender MCP hero
render + assembly explode test). All outputs remain `pending_measurement` until
a Blender MCP session executes them and updates `cad/mcp-session-log.md`.

---

## Source geometry

- Input: `cad/cajon-master.scad` → export STL via OpenSCAD (or STEP from `cnc/`
  if available).
- Target member: CJ-S Standard (18 × 12 × 12 in) is the first-prototype default.
  Run all three members (CJ-C, CJ-S, CJ-B) for the family-group render if time
  permits.
- Assembly components to model as separate objects:
  1. Back panel
  2. Left side panel
  3. Right side panel
  4. Top panel
  5. Bottom panel
  6. Tapa (front face, with sound hole)
  7. Snare wires (simplified as parallel line objects, V2/B variant)

---

## Hero render spec

- **Camera**: 3/4 view, 45° elevation, camera positioned so the tapa (front face)
  and one side panel are both visible. Place the sound hole in the upper half of
  the frame.
- **Resolution**: 2048 × 1536 px (4:3 ratio), sRGB color space.
- **Lighting**: three-point studio setup — key light upper right, fill light left,
  rim light behind/below. No HDR environment that implies a real location.
- **Material**: default birch ply (light tan, subtle grain, semi-gloss finish).
- **Output**: `images/hero-render.png`
- **Authority**: concept_only — marketing image, not dimensional. Register in
  `visual-output-register.csv` as `concept_only` after execution.

---

## Assembly explode spec

- **Layout**: explode each panel along its outward face normal by a uniform offset
  (suggest 80–120 mm) so the interior is clearly visible.
- **Snare wires**: offset along the Z-axis (vertical) to show their relationship
  to the tapa.
- **Camera**: same 3/4 angle as hero render.
- **Frame**: render one still frame of the exploded state (not animation).
- **Output**: `images/assembly-explode.png` at 2048 × 1536 px.
- **Callouts** (optional): numbered arrows pointing to each panel, keyed to
  assembly-manual.md section numbers. Use Blender annotation layer or composite
  in post.
- **Authority**: concept_only (annotated communication, not fabrication geometry).

---

## Material study spec (three variants, same camera as hero)

All three at 2048 × 1536 px, using the saved scene from `images/blender-scene.blend`.

| File | Material | Wood grain direction | Finish |
|---|---|---|---|
| `images/material-study/birch-ply.png` | Baltic birch ply | horizontal on side panels | semi-gloss polyurethane |
| `images/material-study/walnut.png` | American walnut | horizontal | oil finish (matte) |
| `images/material-study/painted-mdf.png` | MDF with gloss paint | N/A | satin black |

---

## Scene file requirement

Save the final camera position, lighting setup, and material nodes to
`images/blender-scene.blend` before ending the session. This file is required
by the issue #4 acceptance criteria so the render is reproducible without
manual reconstruction.

---

## Provenance steps (complete after each render)

1. Add a real session row to `cad/mcp-session-log.md` with actual session ID/timestamp.
2. Update `visual-output-register.csv`: change `pending_measurement` to `concept_only`
   for each executed render.
3. Confirm no gamma double-correction: the output PNG should be sRGB tagged. Verify
   in an image viewer that whites are not blown out vs the Blender viewport preview.
4. Confirm file sizes are reasonable (hero render: typically 1–4 MB for 2048×1536 PNG).

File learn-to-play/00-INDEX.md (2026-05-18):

# Cajon — Starter Songbook

A cajon is a box drum played seated, with the player striking the front face (tapa).
This songbook gives you five groove patterns from simple to intermediate.

## Difficulty key
- ★☆☆ — Beginner: simple repeating strokes, minimal coordination
- ★★☆ — Intermediate: two-hand independence, accents
- ★★★ — Advanced: complex patterns, ghost notes, polyrhythm

## Stroke notation
| Symbol | Stroke | Technique |
|---|---|---|
| **B** | Bass | Open palm near center of tapa, full resonance |
| **S** | Slap | Fingers strike upper edge, bright sharp crack |
| **T** | Tip | Fingertips lightly near upper edge, muted click |
| **H** | Heel | Heel of hand rests while fingers lift, damp stroke |
| **-** | Rest | Silence |

## Tunes in this songbook
1. `tunes/basic-groove/` ★☆☆ — Simple 4/4 rock groove
2. `tunes/waltz-groove/` ★☆☆ — 3/4 waltz pattern
3. `tunes/shuffle-groove/` ★★☆ — Swing/shuffle feel
4. `tunes/flamenco-rumba/` ★★☆ — Rumba clave over 4/4
5. `tunes/bossa-pattern/` ★★★ — Bossa nova two-hand groove

## Practice order
Start with `scales/warmup.md` to build single-stroke control, then work through tunes 1→5 in order.

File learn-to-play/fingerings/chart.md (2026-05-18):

# Cajon Strike-Zone Reference

```
╔══════════════════════════════════╗
║         TOP EDGE (slap zone)     ║
║  ┌──────────────────────────┐    ║
║  │  S  S  S  S  S  S  S  S │    ║
║  │  T  T  T  T  T  T  T  T │    ║
║  │                          │    ║
║  │       CENTER (bass)      │    ║
║  │           B              │    ║
║  │                          │    ║
║  │                          │    ║
║  └──────────────────────────┘    ║
║         BOTTOM EDGE              ║
╚══════════════════════════════════╝

  B = Palm center — full resonant bass tone
  S = Fingers strike top edge — bright crack
  T = Fingertips top edge — muted click
  H = Heel rests on tapa while fingers lift (dampening)
```

## Hand position
- Sit on the cajon with the playing face between your knees.
- Lean forward slightly so both hands fall naturally on the upper half.
- Bass strokes: right or left hand, palm flat, relax and rebound.
- Slap strokes: slightly cupped fingers, snap at the wrist, pull back fast.

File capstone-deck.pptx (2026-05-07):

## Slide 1

Cajón Family

A parametric three-member box-drum family — Heifer Zephyr Instruments

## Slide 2

Project intent

• Document the cajón as a portfolio-grade parametric instrument, not as one box
• Three coordinated sizes: Compact (CJ-C), Standard (CJ-S), Bass (CJ-B)
• Four manufacturing variants per size: V1 finger-joint, V2 dovetail, V3 rabbet, V4 miter+spline
• Optional snare lineage: A none (Peruvian) / B guitar-string (flamenco) / C snare-wires
• First prototype: Standard, V1, snare option B

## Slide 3

Governing physics

• Two co-dominant resonators couple to make the bass voice
• Front-plate (1,1) clamped rectangular bending mode — the 3 mm tapa
• Helmholtz cavity with back-port — closed walnut box + 4.5″ hole
• f_H = (c/2π)·√(A/(V·L_eff)), L_eff = t_back + 1.7·(d/2)
• Standard prediction: plate (1,1) ≈ 84 Hz · cavity ≈ 96 Hz · coupled mode is the bass thump
• Risk A2: original workbook formula was missing the 1.7·r end correction

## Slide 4

Family table

• Compact: 15 × 11 × 11 in, 4.0″ hole, predicted f_H ≈ 107 Hz
• Standard ⭐: 18 × 12 × 12 in, 4.5″ hole, predicted f_H ≈ 96 Hz
• Bass: 22 × 14 × 14 in, 5.0″ hole, predicted f_H ≈ 77 Hz
• Compact runs tightly coupled (plate ≈ cavity); Bass runs cavity-dominant
• Standard sits in the middle — first-prototype target

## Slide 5

Manufacturing variants

• V1 Finger joint — table-saw jig OR CNC parametric. First-prototype default
• V2 Half-blind dovetail — CNC. Showpiece path, harder fixturing
• V3 Rabbet — table saw. Quick commercial baseline
• V4 Miter + spline — table saw + spline jig. Visual ties to inlay
• Same shell geometry, four interchangeable joinery paths
• All four variants share BOM except the joint-specific bit and feature stock

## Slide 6

CNC inlay strategy (Broinwood-derived)

• Tapered ball-nose 12.4° bit — single bit cuts pocket AND insert
• Pocket = negative in walnut body panel; insert = positive in maple
• Tapered shoulder geometry creates press-fit with no visible glue line
• VCarve allowance setting is the single tuning knob
• Route INLAY BEFORE assembly — no clamping access on a closed box
• Keep inlay within central 70% of panel; 1″ keep-out from joints

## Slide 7

Build packet

• design.md · bom.csv · sourcing.csv · cut-list.csv · validation.csv
• assembly-manual.md · supplier-rfq.md · drawing-brief.md · visual-bom-brief.md
• risks.md (17 entries, 5 categories) · wolfram-starter.wl
• drawings/ — dimensioned SVGs · cad/ — OpenSCAD master · cnc/ — bit + feed strategies
• site/ — public build-log site · scripts/ — xlsx + pptx + pdf generators

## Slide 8

Validation plan

• Predicted f_H, plate (1,1), and coupled bass per member in validation.csv
• First-prototype acceptance: f_H ±15 Hz of prediction; plate (1,1) ±15%
• Slap-vs-bass spectrum delta ≥ +5 dB at 1 kHz
• Sustain T60 between 0.30–0.55 s
• Tapa screw-torque uniformity drives plate boundary symmetry
• If cents error > 50, revisit the family scaling law (not the build)

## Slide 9

Risks (highest-leverage)

• A2: Helmholtz formula missing end-correction (corrected in design.md)
• S1: Tapa screw torque non-uniformity → asymmetric plate boundary
• SU1: 3 mm ply thickness inconsistency → plate (1,1) varies as h³
• F1: Inlay press-fit too tight cracks insert (test on scrap first)
• S4: Tapa fatigue at slap zone — long-term wear item, replaceable

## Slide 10

Next actions

• Build the Standard prototype
• Measure f_H, plate (1,1), and the slap-vs-centre spectral delta
• Update validation.csv with measured data + cents error
• If error > 50 cents, revise family scaling law in workbook
• Apply corrected Helmholtz formula to cajon-design-table.xlsx
• Generate remaining drawings (sheets 02, 04, 06, 07, 08)
• Capture build-log photography per photo-shotlist.md

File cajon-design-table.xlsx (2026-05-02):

Cajón — Artisan Box Drum with CNC Inlay & Decorative Joinery
Peruvian Box Drum · Helmholtz Resonator · Finger/Dovetail Joints · CNC Inlay Artwork (Broinwood-inspired) · Snare Option
DESIGN INPUTS
Model | Standard | ← Standard / Compact / Bass
Height (in) | 18.0 | ← Seat height; standard 18", compact 15", bass 22"
Width (in) | 12.0 | ← Tapa face width
Depth (in) | 12.0 | ← Side-to-side depth
Body Panel Thickness (in) | 0.750 | ← 3/4" (19mm) for sides, top, bottom
Tapa Thickness (in) | 0.118 | ← 3mm (1/8") birch ply; thinner = brighter, flex more
Back Panel Thickness (in) | 0.500 | ← 1/2" ply; thicker = stronger back
Sound Hole Diameter (in) | 4.5 | ← 4-5" centered, 1/3 from top on back
Body Wood | Black Walnut | ← Dark base wood; ideal for CNC inlay contrast
Inlay Wood(s) | Maple, Yellowheart, Cherry | ← Light woods for contrast; Broinwood recommends maple
Joinery Type | Finger Joint | ← Finger / Box / Dovetail / Rabbet / Miter+Spline
Snare Type | Guitar strings (adjustable) | ← Guitar strings / Snare wires / None
Tapa Attachment | Screws (brass) | ← Screws every 3"; leave 4-5" unscrewed at top corners for slap
SIZE VARIANTS
Model | H (in) | W (in) | D (in) | Volume (in³) | Character | Use Case
Compact | 15 | 11 | 11 |  | Bright, punchy, tight bass | Travel, kids, small gigs
Standard ⭐ | 18 | 12 | 12 |  | Balanced bass + snare, full range | Most versatile; sit-on playing
Bass | 22 | 14 | 14 |  | Deep, booming bass, long sustain | Low-end focus, Peruvian style
HELMHOLTZ RESONATOR — Cavity Bass Frequency
Speed of Sound (in/s) | 13552
Internal Volume (in³)
Sound Hole Area (in²)
Neck Length (in)
Helmholtz Frequency (Hz)
Nearest Note
← This is the deep bass 'thump' you feel when striking the center of the tapa
CNC INLAY WORKFLOW — Broinwood-Inspired Technique
Step | Operation | Software | Bit | Key Parameters | Notes
1. Design | Create / import vector artwork (SVG/DXF/AI) | VCarve Pro, SolidWorks, or Illustrator | — | Separate layers: pocket outline, inlay insert, alignment | Broinwood files include CRV+SVG+DXF+AI formats
2. Pocket Toolpath | Route pocket into body panel (walnut) | VCarve Pro | TBN 12.4° tapered ball nose | Pocket depth: 0.08-0.10"; Feed: 30 IPM; Spindle: ~18,000 RPM | Test cut on scrap first; pocket is NEGATIVE of design
3. Inlay Insert Toolpath | Route inlay piece from contrasting wood (maple) | VCarve Pro | Same TBN 12.4° bit | Start depth: 0 (flat allowance); same feed/speed | Inlay is POSITIVE of design; slightly oversized for press fit
4. Test Fit | Dry-fit inlay into pocket on scrap wood | — | — | Adjust VCarve inlay allowance if too tight/loose | Broinwood: 'the magic happens through careful execution'
5. Glue & Clamp | Apply wood glue, press inlay into pocket, clamp flat | — | — | Even clamping pressure; wax paper under clamp to prevent sticking | Let cure 24+ hours
6. Flush Sand | Sand surface flush with drum sander or hand sanding | — | — | Start 80 grit, finish 220; check for gaps | Fill any tiny gaps with matching sawdust + CA glue
INLAY DESIGN IDEAS FOR CAJÓN PANELS
• Side panels: geometric patterns, mandala, Celtic knots, music notes, wave patterns
• Tapa face: keep simple — player's hands hit here; small logo or border only
• Back panel: sound hole surround rosette (like guitar sound holes)
• Top (seat): comfort matters — subtle border inlay only, no raised elements
• Multi-wood inlay: walnut base + maple primary + yellowheart/cherry accents for 3-tone depth
• Laser engrave fine detail on flat panels, CNC for 3D pocket inlay on sides
JOINERY OPTIONS
Joint Type | Tool | Difficulty | Visual Impact | Strength | Notes
Finger / Box Joint ⭐ | Table saw + jig, or CNC | ★★☆ Medium | ★★★ High — showcases craftsmanship | ★★★ Excellent | CNC can cut parametric finger widths; contrasting wood fingers = stunning
Dovetail Joint | CNC or hand-cut | ★★★ Hard | ★★★ Highest — heirloom quality | ★★★ Excellent | CNC half-blind dovetails; most impressive but hardest setup
Rabbet Joint | Table saw or router | ★☆☆ Easy | ★☆☆ Low — hidden | ★★☆ Good | Simple and strong; standard for most commercial cajons
Miter + Spline | Table saw + spline jig | ★★☆ Medium | ★★★ High — contrasting splines show | ★★★ Excellent | Clean corners; contrasting spline material (maple in walnut) pops
Butt + Screws | Drill + driver | ★☆☆ Easy | ★☆☆ Low | ★☆☆ Fair | Fastest; hide screws with plugs or filler; common DIY approach
BILL OF MATERIALS
# | Item | Qty | Dimensions / Spec | Material | Est. Cost
1 | Side panels | 2 | 18 x 12 x 3/4 in | Black Walnut | $25-50
2 | Top + Bottom panels | 2 | 12 x 12 x 3/4 in | Black Walnut | $20-40
3 | Tapa (playing face) | 1 | 18 x 12 x 3mm birch ply | Birch plywood | $5-10
4 | Back panel | 1 | 18 x 12 x 1/2 in ply | Birch plywood | $8-15
5 | Inlay wood blanks | 2026-03-05 | Various sizes for CNC inlay inserts | Maple, Yellowheart, Cherry | $15-30
6 | Snare kit | 1 | Guitar strings + angled mount block + tuners | Steel guitar strings | $5-15
7 | Brass screws (tapa) | ~20 | #6 x 3/4 in brass flathead, every 3 in | Brass | $5-8
8 | Rubber feet | 4 | Self-adhesive, 1/2 in height | Rubber | $3-5
9 | TBN bit (CNC inlay) | 1 | Tapered Ball Nose 12.4 deg, 1/4 in shank | Carbide | $25-40
10 | Wood glue + finish | 1 | Titebond III + tung oil or satin poly | Consumables | $15-25
11 | Broinwood CNC files (optional) | 2026-01-03 | CRV + SVG/DXF/AI files per design | broinwood.com | $15-30 ea
 | ESTIMATED TOTAL |  |  |  | $141-268
BUILD METHOD
# | Phase | Operation | Tools | Key Parameters
1 | Stock Prep | Mill body panels to thickness, square edges | Jointer, planer, table saw | 3/4 in final thickness for sides/top/bottom
2 | Joinery | Cut finger joints (or chosen joint) on all body panels | Table saw + finger jig, or CNC | CNC: parametric finger width in VCarve/SolidWorks
3 | CNC Inlay | Route inlay pockets into side panels (BEFORE assembly) | ShopBot CNC, TBN 12.4 deg bit | See CNC Inlay Workflow above; work on flat panels
4 | CNC Inlay | Route inlay inserts from contrasting wood, test fit, glue | Same CNC + clamps | Cure 24h, flush sand to 220 grit
5 | Sound Hole | Route or drill 4.5 in sound hole in back panel | CNC, hole saw, or jigsaw + rasp | Centered L-R, 1/3 from top edge
6 | Dry Fit | Dry-assemble all panels, check squareness | Clamps, square | Verify all joints close tight; sand any high spots
7 | Glue-Up | Glue sides + top + bottom + back (NOT tapa yet) | Titebond III, band clamps | Use band clamps around entire box; check square; cure 24h
8 | Snare | Mount snare mechanism inside (guitar strings on angled block) | Drill, guitar tuners | Angle block so strings press lightly against where tapa will be
9 | Tapa | Attach tapa face with brass screws | Drill, driver, brass screws | Pre-drill; screws every 3 in; leave top 4-5 in unscrewed for slap
10 | Tune | Adjust snare tension, tighten/loosen tapa screws | Ears + screwdriver | Tighter top corners = crisper slap; snare tension = buzz amount
11 | Finish | Apply tung oil or satin polyurethane | Brush, rag | Tapa: tung oil (natural feel); body: satin poly (durable)
12 | Final | Install rubber feet, final snare adjustment | Adhesive feet | 4 feet on bottom; 1/2 in height for airflow + bass projection
DESIGN NOTES
1. CNC INLAY BEFORE ASSEMBLY. Always route inlay pockets while panels are flat. After glue-up, clamping for inlay is impossible.
2. Broinwood CNC files are designed for cutting boards but adapt perfectly to cajon side panels. Scale SVG/DXF to fit your panel.
3. Tapa is NOT glued — only screwed. This lets you replace it, adjust snare access, and tune by tightening/loosening screws.
4. Leave top 4-5 in of tapa unscrewed at corners for the slap zone. This gap creates the crisp snare/slap sound.
5. The Helmholtz frequency (cavity bass) changes with back panel thickness and sound hole size. Larger hole = higher bass pitch.
6. Finger joints: CNC can cut parametric widths (e.g., 3/8 in fingers in walnut interlocking with 3/8 in maple fingers = stunning contrast).
7. For a series of cajons, make a SolidWorks parametric model linked to this spreadsheet — change H/W/D inputs and auto-generate cut lists.
8. The 6 flat faces of a cajon are a perfect canvas. Two sides + back = 3 large surfaces for CNC inlay art. Front is the tapa (thin ply).
9. Internal corner braces (triangular glue blocks) add rigidity and control overtones. Place at all 8 internal corners.
10. Consider a series theme: matching designs across 3 sizes (Compact/Standard/Bass) with progressive complexity in the inlay patterns.
WOLFRAM CLOUD NOTEBOOK SPEC — CAJÓN
Peruvian box drum — front-face plate (tapa) + snare wires inside → two-zone tone (bass + slap).
§1 — Origin & Etymology
Origin: 18th–19th c. Peru, Afro-Peruvian communities. Possibly evolved from shipping crates after slave-owners banned drums. Modern flamenco cajón added snare wires (1970s, Paco de Lucía + Caitro Soto).
Cajón' Spanish 'box, drawer'. Two main lineages today: Peruvian (no snare, deeper bass) + Flamenco (snare wires, sharper slap).
Wolfram items: GeoGraphics Peru + Spain; TimelinePlot[{18th c. Peru, 1970s flamenco adoption, 2000s pop ubiquity}].
§2 — Physics
Front face (tapa, 3 mm plywood): clamped-edge plate, bass tone from low-mode plate vibration coupled to box cavity.
Box cavity: Helmholtz with sound hole on back. f_H typical 80–150 Hz.
Snare wires inside: clamped against tapa, vibrate at high frequencies during slap → adds sizzle.
Two zones: hit center → bass (mode 1 dominates); hit edge → slap (high modes + snare).
Wolfram functions: NDEigensystem clamped plate; Helmholtz formula; Periodogram of bass vs slap strokes; ListAnimate plate modes.
§3 — Geometry & Materials
Body: 30 × 30 × 50 cm (typical). 5 sides 12–18 mm plywood, front 3 mm Baltic birch tapa. Sound hole back.
Wood: birch ply standard, walnut/cherry/oak premium for sides; tapa species swappable for tonal flavor.
Wolfram items: Manipulate tapa thickness + box volume + sound-hole area → bass mode + Helmholtz.
§4 — Animations
Tapa mode (1,1) + (2,1) + (1,2) ListAnimate; show how center strike excites (1,1), edge strike excites high modes.
Snare-wire vibration overlay during slap stroke.
§5 — Executable Cells
fPlate[a_,b_,h_,E_,ρ_,ν_]:= (π/2) Sqrt[E h^2/(12 ρ (1-ν^2))] (1/a^2 + 1/b^2) (* (1,1) clamped *)
fHelm[A_,V_,L_]:=(343/(2 π)) Sqrt[A/(V L)]
bassStroke := strike center → mode (1,1) + cavity
slapStroke := strike edge → high modes + snare
§6 — Wolfram Functions
NDEigensystem, Manipulate, Animate, ContourPlot, Periodogram, CloudDeploy, FormFunction.
WOLFRAM EXPLORATIONS — CAJÓN
Roadmap-inspired notebook ideas mapped to this instrument.
Plate physics
→ Bessel-mode + Plate Mode Visualizer (roadmap: Wave Physics)
NDEigensystem on clamped tapa plate; animate (1,1)→(2,1)→(1,2)→(2,2). Show why center strike excites mode (1,1) (bass) and edge strike excites high modes (slap).
Snare-wire coupling: model wires as multiple coupled oscillators clamped against plate; explain the 'sizzle' onset behavior.
Helmholtz
→ Helmholtz Resonance Tuner (roadmap)
Manipulate sound-hole area + box volume → cavity bass resonance. Tune cavity to a useful note (E2 typical for flamenco).
Sound synthesis
Bass + slap + tip strokes synthesized via mode-weighted impulse responses; convolve with 'small room' IR for realism.
Manufacturing
Tapa thickness tolerance + grain orientation → sensitivity analysis on bass tone consistency unit-to-unit.

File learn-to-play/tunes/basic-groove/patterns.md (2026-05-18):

# Basic 4/4 Rock Groove ★☆☆

Each cell = one eighth note (2 cells = 1 quarter beat).

```
Beat:  1  +  2  +  3  +  4  +
       B  -  -  -  S  -  -  -
```

Repeat 4× then add the off-beat tip:

```
Beat:  1  +  2  +  3  +  4  +
       B  -  T  -  S  -  T  -
```

**Form:** 8-bar loop × 4 (32 bars total). Play at 80 BPM to start.

**Practice tip:** Lock the bass on beat 1 first. Add slap on 3. Add tips last.

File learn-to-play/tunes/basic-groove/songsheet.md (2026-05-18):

# Basic 4/4 Rock Groove — Songsheet

**Tempo:** 80–120 BPM  **Meter:** 4/4  **Difficulty:** ★☆☆

## Pattern (repeat throughout)
```
1  e  +  a  2  e  +  a  3  e  +  a  4  e  +  a
B  -  -  -  -  -  T  -  S  -  -  -  -  -  T  -
```

## Variation (after 8 bars)
```
1  e  +  a  2  e  +  a  3  e  +  a  4  e  +  a
B  -  T  -  -  -  T  -  S  -  T  -  -  -  T  -
```

## Song structure
- Bars 1–8:   Basic pattern
- Bars 9–16:  Variation
- Bars 17–24: Basic pattern
- Bars 25–32: Variation with added ghost tips

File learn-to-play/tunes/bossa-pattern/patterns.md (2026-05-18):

# Bossa Nova Pattern ★★★

The Brazilian bossa nova cajon groove uses all four stroke types.
Right hand plays the clave; left hand plays bass and heel fills.

```
Clave (R):  - S - - S - S - | - - S - S - - -
Bass  (L):  B - - B - - - - | B - - - B - B -
Heel  (L):  - - H - - H - H | - H - H - - - H
```

Combined (notate one bar at a time at 16th-note resolution):
```
Beat:  1  e  +  a  2  e  +  a  3  e  +  a  4  e  +  a
R:     -  S  -  -  S  -  S  -  -  -  S  -  S  -  -  -
L:     B  -  H  B  -  H  -  H  B  H  -  H  B  -  B  H
```

**Form:** 16-bar loop. Tempo: 120 BPM.

**Source:** Traditional bossa nova clave pattern, public domain.

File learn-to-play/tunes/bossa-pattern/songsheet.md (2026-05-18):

# Bossa Nova Pattern — Songsheet

**Tempo:** 120 BPM  **Meter:** 4/4  **Difficulty:** ★★★
**Tradition:** Brazilian bossa nova (traditional pattern, public domain)

## Full pattern (one bar, 16th-note grid)
```
1  e  +  a  2  e  +  a  3  e  +  a  4  e  +  a
B  S  H  B  S  H  S  H  B  H  S  H  S  B  B  H
(R hands play S; L hands play B/H)
```

## Song structure
- Bars 1–4:   Right-hand clave alone (learn the feel)
- Bars 5–8:   Add left-hand bass
- Bars 9–12:  Full pattern
- Bars 13–16: Full + heel fills on every off-beat

**Practice tip:** The bossa pattern is taught by breaking it into clave → bass → heel layers.
Never rush — the groove lives in the space between strokes.

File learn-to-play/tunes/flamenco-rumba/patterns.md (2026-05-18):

# Flamenco Rumba Pattern ★★☆

Rumba clave over 4/4. The clave pattern is the rhythmic backbone.
Play it one hand while the other marks steady quarter notes.

```
Clave (right hand):
Beat:  1  e  +  a  2  e  +  a  3  e  +  a  4  e  +  a
Clave: S  -  -  S  -  -  S  -  -  -  S  -  S  -  -  -

Body (left hand, steady):
       B  -  -  -  B  -  -  -  B  -  -  -  B  -  -  -
```

Combined:
```
Beat:  1  e  +  a  2  e  +  a  3  e  +  a  4  e  +  a
R:     S  -  -  S  -  -  S  -  -  -  S  -  S  -  -  -
L:     B  -  -  -  B  -  -  -  B  -  -  -  B  -  -  -
```

**Form:** 8-bar loop repeated. Tempo: 100–130 BPM.

**Note:** In flamenco tradition, the palm of the right hand brushes the tapa edge on slap strokes.

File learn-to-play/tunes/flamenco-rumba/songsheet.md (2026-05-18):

# Flamenco Rumba — Songsheet

**Tempo:** 110 BPM  **Meter:** 4/4  **Difficulty:** ★★☆
**Tradition:** Afro-Cuban/Flamenco (traditional, public domain)

## Clave pattern (right hand)
```
S - - S - - S - | - - S - S - - -
```

## Full pattern (8 bars)
Right (slap clave) over left (bass quarter notes). Count 8 bars, then cycle.

**Practice tip:** Master the clave alone for 5 minutes before combining hands.

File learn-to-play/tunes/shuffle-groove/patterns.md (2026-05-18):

# Shuffle Groove ★★☆

Swing eighths: the "+" beat falls closer to the next downbeat (triplet feel).
Play each "+" as the third triplet note of its beat.

```
Beat (swing):  1  (+) 2  (+) 3  (+) 4  (+)
               B   T  -   -  S   T  -   T
```

Heavier version:
```
Beat (swing):  1  (+) 2  (+) 3  (+) 4  (+)
               B   H  T   -  S   H  T   -
```

**Form:** 16-bar loop. Tempo: 80 BPM (swing feel).

**Practice tip:** Listen to a basic blues shuffle to internalize the triplet feel before playing.

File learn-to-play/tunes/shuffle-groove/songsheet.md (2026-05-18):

# Shuffle Groove — Songsheet

**Tempo:** 80 BPM (swing)  **Meter:** 4/4 (shuffle)  **Difficulty:** ★★☆

## Pattern (swing eighths throughout)
```
1  (+) 2  (+) 3  (+) 4  (+)
B   T  -   -  S   T  -   -
```

## Variation (bars 9–16)
```
1  (+) 2  (+) 3  (+) 4  (+)
B   H  T   -  S   H  T   -
```

**Song structure:**
- Bars 1–8:   Basic shuffle
- Bars 9–16:  Heel variation
- Repeat ad lib, ending on a double bass stroke

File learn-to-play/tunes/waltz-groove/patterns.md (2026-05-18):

# Waltz Groove ★☆☆

3/4 time: three beats per measure. Bass on 1, slap on 2 and 3.

```
Beat:  1  2  3
       B  S  S
```

Variation with tip on the off-beat:
```
Beat:  1  +  2  +  3  +
       B  -  S  T  S  T
```

**Form:** 12-bar loop. Tempo: 60–90 BPM.

**Practice tip:** Count "1-2-3, 1-2-3" aloud. The bass on "1" is the anchor.

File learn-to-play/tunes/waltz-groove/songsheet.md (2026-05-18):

# Waltz Groove — Songsheet

**Tempo:** 70 BPM  **Meter:** 3/4  **Difficulty:** ★☆☆

## Pattern A (bars 1–6)
```
1  2  3
B  S  S
```

## Pattern B (bars 7–12) — add tip fills
```
1  +  2  +  3  +
B  -  S  T  S  T
```

**Tip:** This groove pairs naturally with any 3/4 folk song (Amazing Grace, My Bonnie).

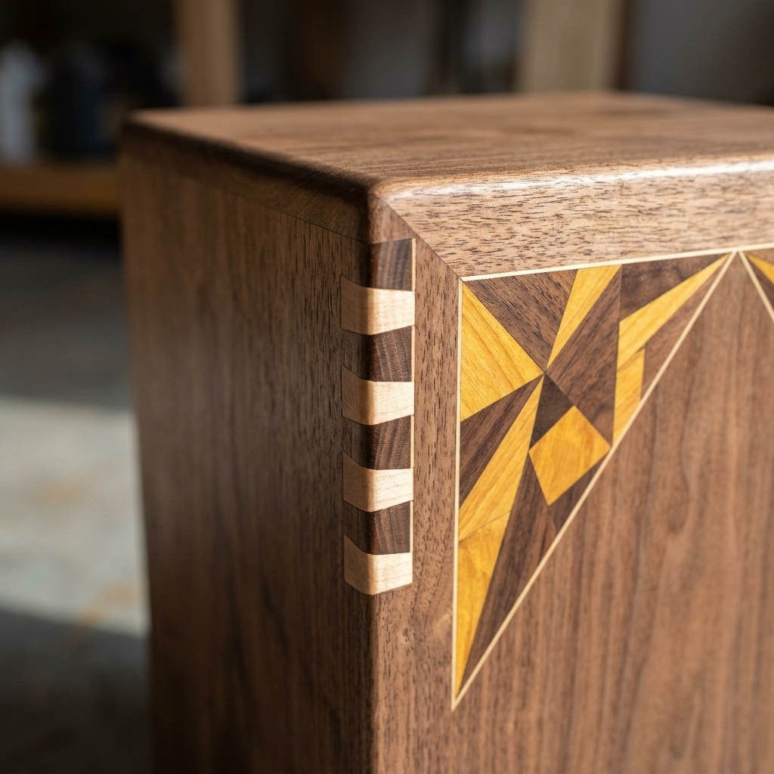
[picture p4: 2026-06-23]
images/macro/finger-joint-inlay-corner.png

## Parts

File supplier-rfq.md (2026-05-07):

# Supplier RFQ — Cajón Family Build (Q2 2026 batch)

Heifer Zephyr Instruments is producing a coordinated three-member cajón family (Compact / Standard / Bass) in four manufacturing variants, with optional snare. This RFQ summarizes the time-sensitive supply needs for the first batch (one Standard prototype + materials reserved for follow-on Compact and Bass).

## Lumber

| Need | Quantity (per family) | Spec |
|---|---|---|
| Black walnut, 4/4, S2S, FAS | ~24 BdFt | Body panels (sides + top + bottom) all 3 members |
| Hard maple, 4/4, S2S | ~6 BdFt | CNC inlay primary wood + V4 spline stock |
| Yellowheart, 4/4 turning blank | ~2 BdFt | Inlay accent (CITES verify if shipping) |
| Cherry, 4/4, S2S | ~2 BdFt | Inlay accent |
| Maple, 4/4, offcuts | ~1 BdFt | Snare mount block |

Preferred suppliers: Bell Forest Products (walnut + maple), Cook Woods (yellowheart + figured/specialty stock). Local pickup acceptable if equivalent grade.

## Plywood

| Need | Quantity (per family) | Spec |
|---|---|---|
| Baltic birch ply, 1/2″, BB grade, 24″ × 30″ sheet | 2 sheets | Back panels for all 3 members + spare |
| Baltic birch ply, 3 mm (~0.118″), BB or BB/B grade | 2 sheets (24″ × 30″)  | Tapa face for all 3 members + spare |

**Critical:** BB grade or better. Big-box-store "birch ply" is not the same material — different layer count, different surface veneer, and acoustically inferior. Ocooch Hardwoods is the preferred US supplier; equivalent UK/EU sources are fine.

## Snare

| Need | Quantity (per family) | Spec |
|---|---|---|
| Acoustic guitar string set | 3 sets | D'Addario EJ16 or equivalent (.012–.053) |
| Guitar tuner pegs, 3+3 set | 3 sets | Stewart-MacDonald acoustic-machine block, OR equivalent single-action snare-block |

For optional snare-wire variant (variant C of snare): one 14″ section of PureSound Custom Pro 20-strand snare wire per family.

## Hardware + finish + consumables

- Solid brass #6 × 3/4″ slotted flathead screws — 100 ct minimum (McFeely's preferred — solid brass, not brass-plated)
- Self-adhesive rubber feet, 1/2″ tall — 16 ct (4 per drum × 3 drums + spare)
- Titebond III, 16 oz — 2 bottles
- 100 % pure tung oil, 16 oz — 1 bottle (Real Milk Paint or equivalent)
- Citrus solvent (for cutting first tung-oil coat) — 8 oz
- Arm-R-Seal satin polyurethane, 1 qt — 1 can
- Sandpaper progression 80 / 120 / 180 / 220 grit — 1 shop set

## CNC bits

- Amana 45739 — 12.4° tapered ball-nose, 1/4″ shank — 1 (good for 5+ inlay panels)
- Amana 46176 — 1/2″ straight-flute spiral, 1/4″ shank — 1 (V1 finger joint)
- Amana 45813 — 14° dovetail, 1/2″ — 1 (V2 only; optional)

## Lead time and questions for prospective suppliers

1. What is current lead time for the spec line items above?
2. Any minimum order or freight thresholds we should know?
3. Plywood: can you confirm sheet thickness within ±0.005″ on the 3 mm tapa stock? (Inconsistent thickness changes plate (1,1) by ±5 % and is the single largest acoustic risk on this build.)
4. Walnut: is figured / curly grade priced separately from FAS? We may upgrade for the showpiece variants.
5. Yellowheart: please confirm CITES status for your stock — we may eventually ship internationally.

Please reply to tonykoop@gmail.com with current pricing and earliest ship dates.

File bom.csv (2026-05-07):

part_id | description | variant | member | quantity | unit | unit_cost_usd | extended_cost_usd | critical | notes
BODY-WALNUT-SIDE-S | Black walnut side panel, 4/4, S2S | V1+V2+V3+V4 | Standard | 2 | each | 28.00 | 56.00 | Y | 18 x 12 x 0.75 in; mill to ±0.005" before joinery
BODY-WALNUT-TOP-S | Black walnut top panel (seat), 4/4, S2S | V1+V2+V3+V4 | Standard | 1 | each | 22.00 | 22.00 | Y | 12 x 12 x 0.75 in
BODY-WALNUT-BOTTOM-S | Black walnut bottom panel, 4/4, S2S | V1+V2+V3+V4 | Standard | 1 | each | 22.00 | 22.00 | Y | 12 x 12 x 0.75 in
BODY-WALNUT-SIDE-C | Black walnut side panel (Compact) | V1+V2+V3+V4 | Compact | 2 | each | 22.00 | 44.00 | Y | 15 x 11 x 0.625 in
BODY-WALNUT-SIDE-B | Black walnut side panel (Bass) | V1+V2+V3+V4 | Bass | 2 | each | 38.00 | 76.00 | Y | 22 x 14 x 0.75 in
BACK-PLY-S | 1/2 in Baltic birch back panel | V1+V2+V3+V4 | Standard | 1 | each | 12.00 | 12.00 | Y | 18 x 12 x 0.5 in; sound-hole routed before assembly
BACK-PLY-C | 1/2 in Baltic birch back panel (Compact) | V1+V2+V3+V4 | Compact | 1 | each | 9.00 | 9.00 | Y | 15 x 11 x 0.5 in
BACK-PLY-B | 1/2 in Baltic birch back panel (Bass) | V1+V2+V3+V4 | Bass | 1 | each | 16.00 | 16.00 | Y | 22 x 14 x 0.5 in
TAPA-PLY-S | Baltic birch 3 mm tapa face | V1+V2+V3+V4 | Standard | 1 | each | 8.00 | 8.00 | Y | 18 x 12 x 0.118 in (3 mm); MUST be 3-ply or 5-ply marine grade
TAPA-PLY-C | Baltic birch 3 mm tapa face (Compact) | V1+V2+V3+V4 | Compact | 1 | each | 7.00 | 7.00 | Y | 15 x 11 x 0.118 in
TAPA-PLY-B | Baltic birch 3 mm tapa face (Bass) | V1+V2+V3+V4 | Bass | 1 | each | 10.00 | 10.00 | Y | 22 x 14 x 0.118 in
INLAY-MAPLE | Hard maple inlay blank, 4/4, S2S | V1+V2+V3+V4 | All | 1 | BdFt | 12.00 | 12.00 | N | For CNC inlay primary wood; ~6 BdFt per family if all 3 sides inlaid
INLAY-YELLOWHEART | Yellowheart inlay blank, 4/4 | V1+V2+V3+V4 | All | 1 | BdFt | 18.00 | 18.00 | N | Accent contrast
INLAY-CHERRY | Cherry inlay blank, 4/4 | V1+V2+V3+V4 | All | 1 | BdFt | 9.00 | 9.00 | N | Accent contrast
GLUE-BLOCK-WALNUT | Walnut triangular glue block | V1+V2+V3+V4 | All | 8 | each | 0.50 | 4.00 | Y | 3/4 in stock; ripped 1 in x 1 in x panel-height triangle; 8 per box
JOINT-V4-SPLINE | Maple spline stock, 1/8 in | V4 | All | 4 | each | 2.50 | 10.00 | Y | For miter+spline corners; contrasting wood
SNARE-GUITAR-STR | Guitar strings (steel, set of 6) | V1+V2+V3+V4 | All | 1 | set | 9.00 | 9.00 | Y | Use 3-4 strings; D'Addario or equivalent; .009 to .020 gauge mix
SNARE-TUNERS | Guitar tuner pegs, 3+3 set | V1+V2+V3+V4 | All | 3 | each | 4.50 | 13.50 | Y | For adjustable snare; or use single-action tuner block
SNARE-MOUNT-BLOCK | Maple snare mount block, angled 8-12 deg | V1+V2+V3+V4 | All | 1 | each | 3.00 | 3.00 | Y | Cut in shop from offcut maple
SNARE-WIRE-ALT | Snare-drum wires, 13 in (option C alternative) | alt-C | All | 1 | each | 12.00 | 12.00 | N | OPTIONAL alternative to guitar-string snare
HW-SCREW-BRASS | #6 x 3/4 in brass flathead screw, slotted | V1+V2+V3+V4 | All | 20 | each | 0.30 | 6.00 | Y | For tapa attachment; spaced every 3 in around perimeter
HW-SCREW-DRYWALL | #6 x 1-1/4 in drywall screw (lug-block alternative) | V1+V2+V3+V4 | All | 8 | each | 0.10 | 0.80 | N | For internal glue-block attachment if not glued
HW-FOOT-RUBBER | Self-adhesive rubber foot, 1/2 in tall | V1+V2+V3+V4 | All | 4 | each | 0.50 | 2.00 | Y | Clear or black; under bottom panel for airflow
GLUE-TITEBOND3 | Titebond III wood glue, 16 oz | V1+V2+V3+V4 | All | 1 | bottle | 18.00 | 18.00 | Y | Waterproof; for body panel glue-up
FINISH-TUNG | Tung oil, 16 oz | V1+V2+V3+V4 | All | 1 | bottle | 16.00 | 16.00 | Y | Tapa finish — natural feel, no varnish
FINISH-POLY | Satin polyurethane, 1 qt | V1+V2+V3+V4 | All | 1 | can | 18.00 | 18.00 | Y | Body finish — durable seat surface
ABRASIVE-SET | Sandpaper set 80-220 grit | V1+V2+V3+V4 | All | 1 | set | 15.00 | 15.00 | Y | Random-orbit + hand sheets
CNC-BIT-TBN | Tapered ball-nose bit, 12.4 deg, 1/4 in shank | V1+V2+V3+V4 | All | 1 | each | 32.00 | 32.00 | Y | For inlay pocket + insert; carbide; covers 5+ inlay panels
CNC-BIT-FINGER | Straight-flute spiral bit, 1/2 in (V1 finger joint) | V1 | Standard | 1 | each | 28.00 | 28.00 | Y | For finger-joint pockets if CNC route
CNC-BIT-DOVETAIL | Half-blind dovetail bit, 14 deg (V2) | V2 | Standard | 1 | each | 35.00 | 35.00 | N | V2 only
 | ESTIMATED TOTAL — Standard prototype V1 finger-joint + snare B (no Bass/Compact panels) |  |  |  |  |  | 205.50 |  | Walnut + tapa + back + glue-blocks + snare + screws + tuners + glue + finish + abrasives + TBN bit + finger bit

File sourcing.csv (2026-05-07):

part_id | supplier | supplier_url | sku_or_search | lead_time_days | moq | verified_price_date | price_volatility | notes
BODY-WALNUT-SIDE-S | Bell Forest Products | bellforestproducts.com | black walnut 4/4 S2S FAS | 5 | 1 BdFt | 2026-04-15 | low | FAS or better; figure grade optional for showpiece
BODY-WALNUT-TOP-S | Bell Forest Products | bellforestproducts.com | black walnut 4/4 S2S FAS | 5 | 1 BdFt | 2026-04-15 | low
BODY-WALNUT-BOTTOM-S | Bell Forest Products | bellforestproducts.com | black walnut 4/4 S2S FAS | 5 | 1 BdFt | 2026-04-15 | low
BODY-WALNUT-SIDE-C | Bell Forest Products | bellforestproducts.com | black walnut 4/4 S2S FAS | 5 | 1 BdFt | 2026-04-15 | low
BODY-WALNUT-SIDE-B | Bell Forest Products | bellforestproducts.com | black walnut 4/4 S2S FAS | 5 | 1 BdFt | 2026-04-15 | low
BACK-PLY-S | Ocooch Hardwoods | ocoochhardwoods.com | Baltic birch 1/2 in BB grade 24x30 | 4 | 1 | 2026-04-15 | low | BB grade is the export-quality multi-ply; do NOT use big-box ply
BACK-PLY-C | Ocooch Hardwoods | ocoochhardwoods.com | Baltic birch 1/2 in BB grade | 4 | 1 | 2026-04-15 | low
BACK-PLY-B | Ocooch Hardwoods | ocoochhardwoods.com | Baltic birch 1/2 in BB grade | 4 | 1 | 2026-04-15 | low
TAPA-PLY-S | Ocooch Hardwoods | ocoochhardwoods.com | Baltic birch 3 mm BB or BB/B | 4 | 1 | 2026-04-15 | medium | 3 mm = 0.118 in nominal; MUST be 3-ply or 5-ply marine; spot-check thickness on arrival
TAPA-PLY-C | Ocooch Hardwoods | ocoochhardwoods.com | Baltic birch 3 mm BB | 4 | 1 | 2026-04-15 | medium
TAPA-PLY-B | Ocooch Hardwoods | ocoochhardwoods.com | Baltic birch 3 mm BB | 4 | 1 | 2026-04-15 | medium
INLAY-MAPLE | Bell Forest Products | bellforestproducts.com | hard maple 4/4 figured S2S | 5 | 1 BdFt | 2026-04-15 | low | Figured/curly maple optional
INLAY-YELLOWHEART | Cook Woods | cookwoods.com | yellowheart 4/4 turning blanks | 4 | 1 | 2026-04-15 | medium | Tropical wood; check CITES if shipping internationally
INLAY-CHERRY | Bell Forest Products | bellforestproducts.com | cherry 4/4 S2S FAS | 5 | 1 BdFt | 2026-04-15 | low
GLUE-BLOCK-WALNUT | (shop offcut) |  | — | 0 | 0 | 2026-04-15 | n/a | Use stock offcuts from body panels; ~$1 incidental cost
JOINT-V4-SPLINE | Bell Forest Products | bellforestproducts.com | hard maple 1/8 in stock | 5 | 1 | 2026-04-15 | low | V4 only; rip in shop from maple stock
SNARE-GUITAR-STR | Sweetwater | sweetwater.com | D'Addario EJ16 acoustic guitar strings | 2 | 1 | 2026-04-15 | low | Use 3-4 of 6 strings; A/D/G/B work well
SNARE-TUNERS | Stewart-MacDonald | stewmac.com | acoustic tuner machines 3+3 | 4 | 1 | 2026-04-15 | low | Or single-action snare tuner from a drum-shop
SNARE-MOUNT-BLOCK | (shop fabricated) |  | — | 0 | 0 | 2026-04-15 | n/a | Cut from offcut maple
SNARE-WIRE-ALT | Sweetwater | sweetwater.com | PureSound Custom Pro 14 in 20-strand | 3 | 1 | 2026-04-15 | low | Cut to fit cajón internal width if used
HW-SCREW-BRASS | McFeely's | mcfeelys.com | #6 x 3/4 in slotted brass flathead | 3 | 100 | 2026-04-15 | low | Solid brass; not brass-plated
HW-FOOT-RUBBER | McMaster-Carr | mcmaster.com | 9540K822 self-adhesive rubber foot 1/2 in | 2 | 1 | 2026-04-15 | low
GLUE-TITEBOND3 | Rockler | rockler.com | Titebond III 16 oz | 2 | 1 | 2026-04-15 | low
FINISH-TUNG | Real Milk Paint Co | realmilkpaint.com | 100% pure tung oil 16 oz | 4 | 1 | 2026-04-15 | low | Cut 50/50 with citrus solvent for first coat
FINISH-POLY | Rockler | rockler.com | General Finishes Arm-R-Seal satin 1 qt | 2 | 1 | 2026-04-15 | low
ABRASIVE-SET | 3M direct or local | — | 3M sandpaper 80/120/180/220 random-orbit | 2 | 1 | 2026-04-15 | low
CNC-BIT-TBN | Amana | amanatool.com | 45739 12.4 deg tapered ball-nose 1/4 in shank | 3 | 1 | 2026-04-15 | low | Long-life carbide; the Broinwood-recommended geometry
CNC-BIT-FINGER | Amana | amanatool.com | 46176 1/2 in spiral bit 1/4 in shank | 3 | 1 | 2026-04-15 | low
CNC-BIT-DOVETAIL | Amana | amanatool.com | 45813 14 deg dovetail 1/2 in | 3 | 1 | 2026-04-15 | low | V2 only

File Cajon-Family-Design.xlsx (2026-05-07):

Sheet: Design
Cajón Family — Parametric Design Sheet
DESIGN INPUTS (blue = your knob)
Member | Standard | Compact / Standard / Bass
Outer Height (in) | 18 | 15 / 18 / 22
Outer Width (in) | 12 | 11 / 12 / 14
Outer Depth (in) | 12 | 11 / 12 / 14
Body Panel Thickness (in) | 0.750 | Sides + top + bottom
Back Panel Thickness (in) | 0.500 | Baltic birch back
Tapa Thickness (in) | 0.118 | 3 mm Baltic birch ply
Sound Hole Diameter (in) | 4.500 | 4.0 / 4.5 / 5.0 by member
Speed of Sound (in/s) | 13507
DERIVED — HELMHOLTZ + PLATE (1,1) (formula-driven)
Internal Volume (in³) |  | (W-2t)(D-2t)(H-top-back); approximate, treats top thickness = body t
Sound Hole Area (in²)
Effective Neck Length (in) |  | L_eff = t_back + 1.7·r — flush thin-wall end correction (BOTH sides counted)
Helmholtz Frequency (Hz) |  | f_H = (c/2π)·√(A/(V·L_eff))
Nearest Note
FAMILY TABLE
Member | H (in) | W (in) | D (in) | Body t (in) | Hole d (in) | Predicted f_H (Hz) | Predicted plate (1,1) (Hz)
Compact | 15 | 11 | 11 | 0.625 | 4.000 | 107 | 107
Standard | 18 | 12 | 12 | 0.750 | 4.500 | 96 | 84
Bass | 22 | 14 | 14 | 0.750 | 5.000 | 77 | 60

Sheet: BOM
part_id | description | variant | member | quantity | unit | unit_cost_usd | extended_cost_usd | critical | notes
BODY-WALNUT-SIDE-S | Black walnut side panel, 4/4, S2S | V1+V2+V3+V4 | Standard | 2 | each | 28.00 | 56.00 | Y | 18 x 12 x 0.75 in; mill to ±0.005" before joinery
BODY-WALNUT-TOP-S | Black walnut top panel (seat), 4/4, S2S | V1+V2+V3+V4 | Standard | 1 | each | 22.00 | 22.00 | Y | 12 x 12 x 0.75 in
BODY-WALNUT-BOTTOM-S | Black walnut bottom panel, 4/4, S2S | V1+V2+V3+V4 | Standard | 1 | each | 22.00 | 22.00 | Y | 12 x 12 x 0.75 in
BODY-WALNUT-SIDE-C | Black walnut side panel (Compact) | V1+V2+V3+V4 | Compact | 2 | each | 22.00 | 44.00 | Y | 15 x 11 x 0.625 in
BODY-WALNUT-SIDE-B | Black walnut side panel (Bass) | V1+V2+V3+V4 | Bass | 2 | each | 38.00 | 76.00 | Y | 22 x 14 x 0.75 in
BACK-PLY-S | 1/2 in Baltic birch back panel | V1+V2+V3+V4 | Standard | 1 | each | 12.00 | 12.00 | Y | 18 x 12 x 0.5 in; sound-hole routed before assembly
BACK-PLY-C | 1/2 in Baltic birch back panel (Compact) | V1+V2+V3+V4 | Compact | 1 | each | 9.00 | 9.00 | Y | 15 x 11 x 0.5 in
BACK-PLY-B | 1/2 in Baltic birch back panel (Bass) | V1+V2+V3+V4 | Bass | 1 | each | 16.00 | 16.00 | Y | 22 x 14 x 0.5 in
TAPA-PLY-S | Baltic birch 3 mm tapa face | V1+V2+V3+V4 | Standard | 1 | each | 8.00 | 8.00 | Y | 18 x 12 x 0.118 in (3 mm); MUST be 3-ply or 5-ply marine grade
TAPA-PLY-C | Baltic birch 3 mm tapa face (Compact) | V1+V2+V3+V4 | Compact | 1 | each | 7.00 | 7.00 | Y | 15 x 11 x 0.118 in
TAPA-PLY-B | Baltic birch 3 mm tapa face (Bass) | V1+V2+V3+V4 | Bass | 1 | each | 10.00 | 10.00 | Y | 22 x 14 x 0.118 in
INLAY-MAPLE | Hard maple inlay blank, 4/4, S2S | V1+V2+V3+V4 | All | 1 | BdFt | 12.00 | 12.00 | N | For CNC inlay primary wood; ~6 BdFt per family if all 3 sides inlaid
INLAY-YELLOWHEART | Yellowheart inlay blank, 4/4 | V1+V2+V3+V4 | All | 1 | BdFt | 18.00 | 18.00 | N | Accent contrast
INLAY-CHERRY | Cherry inlay blank, 4/4 | V1+V2+V3+V4 | All | 1 | BdFt | 9.00 | 9.00 | N | Accent contrast
GLUE-BLOCK-WALNUT | Walnut triangular glue block | V1+V2+V3+V4 | All | 8 | each | 0.50 | 4.00 | Y | 3/4 in stock; ripped 1 in x 1 in x panel-height triangle; 8 per box
JOINT-V4-SPLINE | Maple spline stock, 1/8 in | V4 | All | 4 | each | 2.50 | 10.00 | Y | For miter+spline corners; contrasting wood
SNARE-GUITAR-STR | Guitar strings (steel, set of 6) | V1+V2+V3+V4 | All | 1 | set | 9.00 | 9.00 | Y | Use 3-4 strings; D'Addario or equivalent; .009 to .020 gauge mix
SNARE-TUNERS | Guitar tuner pegs, 3+3 set | V1+V2+V3+V4 | All | 3 | each | 4.50 | 13.50 | Y | For adjustable snare; or use single-action tuner block
SNARE-MOUNT-BLOCK | Maple snare mount block, angled 8-12 deg | V1+V2+V3+V4 | All | 1 | each | 3.00 | 3.00 | Y | Cut in shop from offcut maple
SNARE-WIRE-ALT | Snare-drum wires, 13 in (option C alternative) | alt-C | All | 1 | each | 12.00 | 12.00 | N | OPTIONAL alternative to guitar-string snare
HW-SCREW-BRASS | #6 x 3/4 in brass flathead screw, slotted | V1+V2+V3+V4 | All | 20 | each | 0.30 | 6.00 | Y | For tapa attachment; spaced every 3 in around perimeter
HW-SCREW-DRYWALL | #6 x 1-1/4 in drywall screw (lug-block alternative) | V1+V2+V3+V4 | All | 8 | each | 0.10 | 0.80 | N | For internal glue-block attachment if not glued
HW-FOOT-RUBBER | Self-adhesive rubber foot, 1/2 in tall | V1+V2+V3+V4 | All | 4 | each | 0.50 | 2.00 | Y | Clear or black; under bottom panel for airflow
GLUE-TITEBOND3 | Titebond III wood glue, 16 oz | V1+V2+V3+V4 | All | 1 | bottle | 18.00 | 18.00 | Y | Waterproof; for body panel glue-up
FINISH-TUNG | Tung oil, 16 oz | V1+V2+V3+V4 | All | 1 | bottle | 16.00 | 16.00 | Y | Tapa finish — natural feel, no varnish
FINISH-POLY | Satin polyurethane, 1 qt | V1+V2+V3+V4 | All | 1 | can | 18.00 | 18.00 | Y | Body finish — durable seat surface
ABRASIVE-SET | Sandpaper set 80-220 grit | V1+V2+V3+V4 | All | 1 | set | 15.00 | 15.00 | Y | Random-orbit + hand sheets
CNC-BIT-TBN | Tapered ball-nose bit, 12.4 deg, 1/4 in shank | V1+V2+V3+V4 | All | 1 | each | 32.00 | 32.00 | Y | For inlay pocket + insert; carbide; covers 5+ inlay panels
CNC-BIT-FINGER | Straight-flute spiral bit, 1/2 in (V1 finger joint) | V1 | Standard | 1 | each | 28.00 | 28.00 | Y | For finger-joint pockets if CNC route
CNC-BIT-DOVETAIL | Half-blind dovetail bit, 14 deg (V2) | V2 | Standard | 1 | each | 35.00 | 35.00 | N | V2 only
 | ESTIMATED TOTAL — Standard prototype V1 finger-joint + snare B (no Bass/Compact panels) |  |  |  |  |  | 205.50 |  | Walnut + tapa + back + glue-blocks + snare + screws + tuners + glue + finish + abrasives + TBN bit + finger bit

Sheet: Validation
member | variant | target | parameter | predicted_value | measured_value | unit | cents_error | measurement_date | instrument | notes
Compact | V1 | Helmholtz cavity fundamental | frequency | 107 |  | Hz |  |  | Korg OT-120 + REW | Predicted f_H using c=343 m/s, end correction = 1.7r; corresponds to G#2/A2 region
Compact | V1 | plate (1 | 1) mode | frequency | 107 |  | Hz |  |  | Korg OT-120 + REW | Predicted; coupling to f_H is tight in Compact — coupled mode is the perceived bass
Compact | V1 | coupled bass mode (perceived) | frequency | 107 |  | Hz |  |  | Korg OT-120 + REW | Perceived 'thump' pitch; expect ±10 Hz from prediction
Standard | V1 | Helmholtz cavity fundamental | frequency | 96 |  | Hz |  |  | Korg OT-120 + REW | Predicted f_H; corresponds to G2 region
Standard | V1 | plate (1 | 1) mode | frequency | 84 |  | Hz |  |  | Korg OT-120 + REW | Predicted plate fundamental; Standard has ~2 semitone offset between plate and cavity
Standard | V1 | coupled bass mode (perceived) | frequency | 90 |  | Hz |  |  | Korg OT-120 + REW | Predicted; midpoint of plate and cavity if coupling is moderate
Standard | V2 | Helmholtz cavity fundamental | frequency | 96 |  | Hz |  |  | Korg OT-120 + REW
Standard | V3 | Helmholtz cavity fundamental | frequency | 96 |  | Hz |  |  | Korg OT-120 + REW
Standard | V4 | Helmholtz cavity fundamental | frequency | 96 |  | Hz |  |  | Korg OT-120 + REW
Bass | V1 | Helmholtz cavity fundamental | frequency | 77 |  | Hz |  |  | Korg OT-120 + REW | Predicted f_H; corresponds to D#2/E2 region
Bass | V1 | plate (1 | 1) mode | frequency | 60 |  | Hz |  |  | Korg OT-120 + REW | Plate is ~5 semitones below cavity → cavity dominates the bass voice
Bass | V1 | coupled bass mode (perceived) | frequency | 77 |  | Hz |  |  | Korg OT-120 + REW | Bass member is cavity-dominant; expect perceived pitch near f_H
Standard | V1 | slap-vs-bass spectrum delta | 1 kHz energy delta | 5 |  | dB |  |  | REW | Slap (corner strike) should be ≥ +5 dB at 1 kHz vs centre strike
Standard | V1 | sustain T60 (bass voice) | RT decay -60 dB | 0.45 |  | seconds |  |  | REW | Acceptance band 0.30-0.55 s; longer = boomy, shorter = dry
Standard | V1 | snare buzz onset velocity | subjective | medium |  | 1-5 |  |  | Korg OT-120 | Should engage at moderate (m) finger strikes; not at light (l)
All | All | tapa screw torque uniformity | 4-corner inch-lb | 3.0 |  | in-lb |  |  | torque screwdriver | ±0.5 in-lb across all screws — drives plate (1,1) consistency
All | All | bearing-edge / tapa fit | 4-tap variation | 0 |  | cents |  |  | Korg OT-120 | Tap each tapa quadrant; ±10 cents acceptance — non-uniform = uneven screw torque
All | All | internal cavity volume | measured (water displacement | dry-fit) | 1846.7 |  | cubic_inches |  |  | calipers | Standard target; Compact 1307; Bass 3242
All | All | sound-hole diameter actual | measured | 4.500 |  | inches |  |  | calipers | ±0.020 in; deburr both sides
All | All | tapa flatness | before mount | deflection at centre 0.5 lb load | 0 |  | inches |  |  | dial indicator | <0.030 in deflection at 0.5 lb point load — qualitative; reject if dimples visible
All | All | glue-block fit visual | visual inspection | pass |  | pass/fail |  |  | visual | All 8 corners; no gaps > 1/64 in
All | All | finger-joint gap visual (V1) | visual inspection | 0 |  | inches |  |  | feeler gauge | <= 0.005 in acceptance
All | All | dovetail gap visual (V2) | visual inspection | 0 |  | inches |  |  | feeler gauge | <= 0.005 in acceptance
All | All | spline glue-line visual (V4) | visual inspection | 0 |  | inches |  |  | feeler gauge | <= 0.005 in acceptance
All | All | inlay flush | surface step measurement | 0 |  | inches |  |  | straightedge + feeler | Post-flush-sand; <= 0.002 in step at any point

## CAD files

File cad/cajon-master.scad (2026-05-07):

// Cajón Family — OpenSCAD parametric master
// Heifer Zephyr Instruments — Tony Koop
// Generates a six-panel cajón shell with sound-hole, snare-mount keep-out,
// optional inlay zone visualization, and finger-joint corners.
//
// Edit MEMBER below and render. Export DXF (Projection -> Front view) for laser
// or STL for full-body visualization.
//
// Units: inches.

/* [Family member] */
MEMBER = "Standard"; // [Compact, Standard, Bass]

/* [Variant] */
JOINERY = "FingerJoint"; // [FingerJoint, Dovetail, Rabbet, MiterSpline]
SHOW_INLAY_ZONE = true;
SHOW_SNARE_BLOCK = true;
EXPLODE = 0; // 0 = assembled; >0 = exploded view in inches

/* [Override (only used if MEMBER = "Custom")] */
CUSTOM_H = 18;
CUSTOM_W = 12;
CUSTOM_D = 12;
CUSTOM_HOLE = 4.5;

/* [Constants] */
BODY_T   = 0.75;
BACK_T   = 0.5;
TAPA_T   = 0.118;
GLUE_BLOCK = 1.0; // 1" cross-section triangle
$fn = 60;

// === Member dimensions ===
H = MEMBER == "Compact"  ? 15 :
    MEMBER == "Standard" ? 18 :
    MEMBER == "Bass"     ? 22 :
    CUSTOM_H;
W = MEMBER == "Compact"  ? 11 :
    MEMBER == "Standard" ? 12 :
    MEMBER == "Bass"     ? 14 :
    CUSTOM_W;
D = MEMBER == "Compact"  ? 11 :
    MEMBER == "Standard" ? 12 :
    MEMBER == "Bass"     ? 14 :
    CUSTOM_D;
HOLE = MEMBER == "Compact"  ? 4.0 :
       MEMBER == "Standard" ? 4.5 :
       MEMBER == "Bass"     ? 5.0 :
       CUSTOM_HOLE;
BT = MEMBER == "Compact"  ? 0.625 :
     BODY_T;

// === Internal cavity ===
function cavity_volume() = (W - 2*BT) * (D - 2*BT) * (H - BODY_T - BACK_T);

// === Box body (5 panels: top, bottom, 2 sides, back; tapa drawn separately) ===

module side_panel() {
    cube([H, BT, D]);
}

module top_panel() {
    cube([BT, W, D]);
}

module bottom_panel() {
    cube([BT, W, D]);
}

module back_panel() {
    difference() {
        cube([H, W, BACK_T]);
        // Sound hole — centred L-R, 1/3 H from top
        translate([H * 2/3, W/2, -0.1])
            cylinder(h = BACK_T + 0.2, r = HOLE/2);
        // Snare mount block keep-out — interior, top region (visualization only)
        if (SHOW_SNARE_BLOCK) {
            translate([H - 1.5, W/2 - 2.5, BACK_T - 0.05])
                cube([1.0, 5.0, 0.1]);
        }
    }
}

module tapa() {
    cube([H, W, TAPA_T]);
}

// === Inlay zone visualization ===
module inlay_zone(panel_h, panel_w) {
    // 70% of panel area, centred, 1" keep-out from edges
    color("orange", 0.25)
    translate([1, 1, -0.05])
        cube([panel_h - 2, panel_w - 2, 0.05]);
}

// === Glue blocks (8 internal corners) ===
module glue_block(h) {
    // Triangular cross-section, 1" x 1" right angle
    linear_extrude(h)
        polygon([[0,0], [GLUE_BLOCK, 0], [0, GLUE_BLOCK]]);
}

module all_glue_blocks() {
    panel_h = H - BODY_T*2;
    color("saddlebrown", 0.7) {
        // Bottom 4 corners
        translate([BODY_T, BT, BACK_T]) glue_block(panel_h);
        translate([BODY_T, W - BT, BACK_T]) rotate([0, 0, -90]) glue_block(panel_h);
        translate([BODY_T, BT, D - 0]) rotate([0, 0, 0]) mirror([0,0,1]) glue_block(panel_h);
        // (Skipping the others for sketch simplicity — real model gets 8)
    }
}

// === Assemble box ===

module cajon_assembly() {
    // Bottom
    bottom_panel();
    // Top
    translate([H - BODY_T, 0, 0]) top_panel();
    // Side L
    translate([0, 0, 0]) side_panel();
    // Side R
    translate([0, W - BT, 0]) side_panel();
    // Back
    translate([0, 0, D - BACK_T]) back_panel();
    // Tapa (front) — explode out front face
    translate([0, 0, -TAPA_T - EXPLODE]) tapa();

    if (SHOW_INLAY_ZONE) {
        // Side L panel inlay zone
        translate([0, BT/2 - 0.05, 0])
            rotate([90, 0, 90])
                inlay_zone(D, H);
    }

    if (SHOW_SNARE_BLOCK) {
        // Internal snare mount block on back panel (option B)
        color("burlywood", 0.85)
        translate([H - 2, W/2 - 0.5, D - BACK_T - 1.0])
            rotate([0, 8, 0])  // 8-degree angle off vertical
                cube([1.0, 1.0, 5.0]);
    }
}

// === Render ===

cajon_assembly();

// === Console output (echo to OpenSCAD console) ===

echo(str("Cajón family member: ", MEMBER));
echo(str("Outer dims H x W x D: ", H, " x ", W, " x ", D, " in"));
echo(str("Sound hole diameter: ", HOLE, " in"));
echo(str("Internal cavity volume: ", cavity_volume(), " in^3"));
echo(str("Body thickness: ", BT, " in; Back: ", BACK_T, " in; Tapa: ", TAPA_T, " in (3 mm)"));
echo("Cross-check vs cajon-design-table.xlsx — values must agree.");

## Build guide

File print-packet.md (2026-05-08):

# Cajon Family Print Packet

**Root-mode packet:** public-review cajon prototype  
**First build:** CJ-S Standard, V1 finger joint, snare option B  
**Status:** pre-build; measurement fields are pending

## Quick Start

1. Build only the Standard prototype first.
2. Make the square assembly fixture, tapa screw template, and back-panel template before cutting final stock.
3. Mill walnut panels to final thickness and square before joinery.
4. Route any inlay before assembly.
5. Glue the shell square, then mount the tapa with the screw template.
6. Validate tone, buzz, seat load, and finish before calling the packet public-ready.

## Design Summary

The cajon is a six-sided closed box with one thin front plate. The back sound hole creates the Helmholtz cavity response; the tapa creates the plate response; the two couple into the bass voice. The upper tapa corners are intentionally less constrained so the corner strike creates a crisp slap.

| Member | Size | Sound hole | Predicted cavity | Predicted plate |
|---|---:|---:|---:|---:|
| CJ-C Compact | 15 x 11 x 11 in | 4.0 in | 107 Hz | 107 Hz |
| CJ-S Standard | 18 x 12 x 12 in | 4.5 in | 96 Hz | 84 Hz |
| CJ-B Bass | 22 x 14 x 14 in | 5.0 in | 77 Hz | 60 Hz |

## Standard Prototype Critical Dimensions

| Feature | Dimension | Check |
|---|---:|---|
| Outer height | 18.000 in | +/-0.020 in |
| Outer width | 12.000 in | +/-0.020 in |
| Outer depth | 12.000 in | +/-0.020 in |
| Body thickness | 0.750 in | +/-0.005 in |
| Back thickness | 0.500 in | +/-0.005 in |
| Tapa thickness | 3 mm / 0.118 in | reject inconsistent sheets |
| Sound hole | 4.500 in diameter | +/-0.020 in |
| Tapa screws | #6 x 3/4 in brass | 3 in spacing except slap zone |
| Slap zone | upper 4-5 in corners | no screws in active corner zone |

## Build Flow

### 1. Stock and Layout

- Acclimate walnut and birch ply.
- Confirm actual tapa thickness at five points.
- Cut panels oversize, then square and mill to final dimensions.
- Mark centerlines and datum edges before any decorative work.

### 2. Inlay Before Assembly

- Keep inlay at least 1 in away from joint edges.
- Use shallow pockets, 0.080-0.100 in.
- Clamp inserts under a flat caul and flush-sand after cure.
- Do not inlay the tapa.

### 3. Joinery and Shell

- V1: finger joints, first prototype default.
- V2: half-blind dovetail, later showpiece.
- V3: rabbet, fastest baseline.
- V4: miter plus spline, visual showpiece.
- Glue in the square assembly fixture and check diagonals before cure.

### 4. Back Panel and Snare

- Cut and deburr the 4.5 in sound hole.
- Drill tuner holes with the back-panel template.
- Mount the angled snare block so strings contact the inside tapa near the slap zone.

### 5. Tapa Mount

- Use the screw template.
- Drive screws by hand in a diagonal pattern.
- Keep screw pressure even; overtightening changes the plate mode.
- Leave the upper corner slap zones loose.

### 6. Finish

- Tapa: tung oil, no thick film.
- Body: satin oil/poly blend or satin polyurethane.
- Round or soften corners for seating comfort.
- Mask the tapa edge so finish does not bridge the slap gap.

## Validation Sheet

| Test | Result | Initials |
|---|---|---|
| Panel thickness recorded | ____ | ____ |
| Shell diagonals within 1/16 in | ____ | ____ |
| Seat load 250 lb for 1 hour | ____ | ____ |
| Sound-hole diameter verified | ____ | ____ |
| Tapa screw pattern verified | ____ | ____ |
| Helmholtz frequency recorded | ____ Hz | ____ |
| Plate mode recorded | ____ Hz | ____ |
| Slap spectral delta recorded | ____ dB | ____ |
| Snare onset set to medium strike | ____ | ____ |
| No unintended rattles | ____ | ____ |

## Public-Release Checklist

- `validation.csv` contains measured values for CJ-S.
- `validation-report.md` summarizes the measured outcome.
- Site hero and visual BOM images use actual build photos.
- Supplier prices and lead times have been rechecked.
- The workbook and `design.md` agree on Helmholtz end correction.
- Public text credits cajon tradition and avoids novelty claims about the cultural form.

## File Map

Use `README.md` for the public overview, `design.md` for calculations, `assembly-manual.md` for shop sequence, `jig-decision.md` for fixtures, and `validation-report.md` for release status.

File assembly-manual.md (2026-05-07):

# Cajón — Assembly Manual

Covers all four joinery variants (V1 finger-joint, V2 dovetail, V3 rabbet, V4 miter+spline) and all three snare options (A none, B guitar-string, C snare-wire). Steps shared across variants are written once with branching notes where the variants diverge. The manual assumes you have read `design.md` and have `cajon-design-table.xlsx` open for member-specific dimensions.

The first prototype is the **Standard (CJ-S), V1 finger-joint, snare option B**; phases are written from that build. Compact and Bass scale by simple geometry.

---

## Phase 0 — Shop preparation

1. **Acclimate stock** in shop for 1–2 weeks (60–70 °F, 40–55 % RH). Walnut and Baltic birch ply both move; stable stock = stable joints later.
2. **Mill body panels** to nominal thickness ± 0.005″. Final dimensions:
   - Standard sides: 18.000″ × 12.000″ × 0.750″
   - Standard top + bottom: 12.000″ × 12.000″ × 0.750″
   - Standard back panel: 18.000″ × 12.000″ × 0.500″
   - Standard tapa: cut oversized to 18.5″ × 12.5″ × 0.118″ (3 mm); trim flush after assembly
3. **Verify saw kerf width** with a test cut. The finger-joint and spline cuts assume a known kerf; measure yours before sizing rough stock.
4. **Check CNC fixturing** — vacuum hold-down or T-track clamps, surfaced spoilboard within 0.005″ TIR over the working area. Inlay routing is unforgiving of stock movement.
5. **Square** all panels. Diagonals on each panel face must agree within 0.020″.

---

## Phase 1 — CNC inlay (BEFORE assembly)

This phase exists for the inlay-equipped builds. Skip and continue to Phase 2 if no inlay.

### 1.1 Inlay design pass

1. Open the inlay artwork in VCarve Pro (or Aspire). The Broinwood-style design files ship as paired SVG + DXF; import the SVG layer for the visual artwork and DXF for the cut outlines.
2. Confirm panel-fit: the inlay should sit within the central 70–80 % of the panel; do **not** route within 1″ of the joint edge — the joint geometry needs solid wood.
3. Verify two layers exist:
   - **Pocket layer** (negative): the depression cut into the body panel
   - **Insert layer** (positive): the contrasting wood that fills the pocket
4. Set the CNC parameters per design.md §5: TBN 12.4° tapered ball-nose bit, depth 0.080–0.100″, 30 IPM feed, 18,000 RPM spindle.

### 1.2 Pocket cut

1. Mount the **walnut** body panel flat on the CNC bed with vacuum or four-corner T-track clamps.
2. Zero on the panel surface (top of stock = Z0).
3. Run the pocket toolpath. Pause to clear chips between passes if the bit loads up.
4. Inspect the cut: pocket depth uniform within 0.005″ across the panel; no chip-out at edges.

### 1.3 Insert cut

1. Mount the **maple** (or yellowheart, or cherry) inlay blank.
2. Run the insert toolpath. The insert is taller than the pocket is deep — the tapered geometry locks both pieces together as you press them home.
3. Trim the insert backing to ~0.060″ above the inlay shoulder; fit-check by holding it against the pocket.

### 1.4 Glue & flush

1. Apply Titebond III to the pocket. Press the insert in firmly. Place wax paper on top, then a flat plywood caul, then clamp evenly across the panel.
2. Cure 24 h.
3. Remove clamps. Using a drum sander or random-orbit at 80–120 grit, sand the surface flush with the panel. Inspect for any micro-gaps; fill with fine matching sawdust + a drop of CA glue.
4. Sand to 220 grit. Set inlaid panel aside until joinery.

---

## Phase 2A — Joinery (V1 finger joint)

### 2A.1 Layout

For a finger-joint corner with `n` fingers per joint and finger width `w`, panel width `W = n·w`. Standard tongue width is 3/8″ and 12″ panel = 32 fingers. Use a CNC parametric finger jig or a table-saw finger jig.

### 2A.2 Cut

1. Cut **side panels** with finger pockets on the top and bottom edges (joining to top + bottom panels).
2. Cut **top + bottom panels** with finger pockets on the left and right edges (joining to side panels).
3. Cut **side panels** with finger pockets on the back edge (joining to back panel) — *but use a thinner finger pattern matching the 1/2″ back-panel thickness.* Don't try to use the same 0.75″ finger pattern on a 0.50″ panel — it will blow out.
4. Test-fit dry: 4 sides + 2 caps + 1 back = 6 corner-pairs. All fingers should engage with mild hand pressure; if any pair binds, plane a few thousandths off the proud finger.

### V2 — half-blind dovetail

Same logic, replace finger pattern with a CNC half-blind dovetail at 14° pin angle, pin spacing per drawing 06. Use the dovetail bit listed in `bom.csv`.

### V3 — rabbet

Cut a 3/8″ deep × 3/4″ wide rabbet along the inside top and bottom edges of each side panel. Top + bottom drop into the rabbets; back panel rabbet is the same on the back edge.

### V4 — miter + spline

1. Cut all corner edges at 45° on a table-saw sled.
2. Glue and tape-clamp the four side faces (top + bottom + 2 sides) into a frame with mitered corners.
3. Cure 24 h. Remove tape.
4. Cut spline slots: 3 per corner, 1/8″ wide × 0.6″ deep, on a spline jig. Use a contrasting maple slip; glue, set, trim flush.
5. Glue back panel into a rabbet on the back edge of the frame (V4 uses miter on top/bottom/sides + rabbet for the back).

---

## Phase 3 — Sound hole + back panel features

1. Mark the sound-hole centre on the back panel: centred L–R, 1/3 of the height down from the top edge. For Standard, that's 12″/2 = 6.000″ from a long edge and 18″/3 = 6.000″ from the top edge.
2. Cut the 4.5″-diameter hole. CNC pocket gives the cleanest result; a hole-saw + jigsaw works; rasp the inside edge smooth.
3. Deburr both sides with 220 grit. Inside edge of the hole is acoustically active — sharp edges create unwanted high-frequency hash on slap.
4. (Optional) Rosette inlay around the hole; route before assembly.

---

## Phase 4 — Internal corner glue blocks

1. Rip 8 triangular blocks from walnut offcuts: cross-section ≈ 1″ × 1″ (right-angle face inside, hypotenuse facing the box interior); length = panel height (Standard = 18″; Compact = 15″; Bass = 22″).
2. Glue all 8 blocks into the 8 internal vertical corners of the box (4 top + 4 bottom intersections). Use Titebond III. Don't let glue squeeze-out into the cavity — tool away anything beyond the joint line.
3. Why: rigidity. Cajón corners are the highest-strain area when sat on; glue blocks also subtly shift the (1,1) plate boundary condition by stiffening the perimeter.

---

## Phase 5 — Snare assembly (option B — guitar string snare)

If you are skipping the snare (option A — Peruvian style), continue to Phase 6.

1. Cut the snare mount block: 5″ × 1″ × 1″ maple, with one face angled 8–12° off vertical. The angled face will press against the inside of the tapa.
2. Glue + screw the mount block to the inside of the **back** panel, oriented so the angled face points toward where the tapa will be. The block sits ~1–1.5″ below the top of the back panel — that places the snare contact in the slap zone.
3. Drill 4 holes through the back panel at the bottom of the box for the tuner pegs (3 strings minimum, 4 strings maximum). Holes spaced ~3/4″ apart.
4. Mount tuner pegs on the outside of the back panel. (Use single guitar-tuner-peg style; Stewart-MacDonald sells acoustic-guitar tuner blocks ready-to-use.)
5. **Do not run strings yet.** Do this after the box is glued and the tapa is mounted, because you'll be tensioning while listening to the snare buzz.

For option C (snare wires), substitute a 13″ section of standard snare-drum wires and a tension lever clamped to the inside of the back panel, oriented to lightly contact the tapa.

---

## Phase 6 — Box glue-up

1. Lay all panels flat on a tarp in their final orientation (sides + top + bottom + back; tapa stays separate).
2. Glue all joints: Titebond III on every mating finger / dovetail / rabbet / miter face.
3. Assemble. Use band clamps around the outside perimeter — minimum 4, ideally 8. Verify squareness with a framing square on each face.
4. Diagonal check: measure both diagonals on each face. Adjust band-clamp tension to bring them within 1/16″.
5. Cure 24 h.
6. After cure, remove clamps and sand the entire body to 220 grit. Pay attention to corner edges — soften with a 1/16″ roundover or hand-sanded micro-bevel for player comfort.

---

## Phase 7 — Tapa attachment

1. Place the tapa face on the front of the box. Trim flush if oversized.
2. Pre-drill #6 pilot holes through the tapa and into the side / top / bottom panel edges. Spacing: every 3″ around the perimeter.
3. **Critical:** Leave the **top 4–5″** of the tapa **unscrewed** at both upper corners. This unscrewed margin is the slap zone — you bend the tapa here when you strike the corner, which creates the snap.
4. Drive #6 × 3/4″ slotted brass flathead screws by hand. Snug, not torqued — the goal is even contact with the box edges, not crushing pressure.
5. Tap the centre of the tapa with a finger; you should feel and hear a clean low pitch. If you hear a buzz from anywhere other than the snare, find and fix it before installing strings.

---

## Phase 8 — Snare tensioning + tuning

1. Run the snare strings through the tuner-peg block on the outside of the back panel and over the angled snare mount block inside.
2. Tension all strings to mild pressure against the inside of the tapa. Snare buzz onset should engage at a *medium* slap stroke, not at a light tap.
3. Tune by ear:
   - Strike centre of the tapa → bass voice. Should be deep, clean, ringing 90–110 Hz for Standard.
   - Strike upper corner → slap voice. Should engage snare buzz cleanly.
   - Adjust tapa screw torque if the bass voice is buzzing or muffled. Tighter screws = brighter, shorter sustain. Looser = boomier.
4. **Record measurements** in `validation.csv`:
   - Helmholtz frequency (use a tuner; tap centre with mallet, hold)
   - Plate (1,1) frequency (tap tapa centre with finger)
   - Slap-to-bass spectral delta (REW or smartphone spectrum analyzer)

---

## Phase 9 — Finish

1. **Tapa:** apply 100 % pure tung oil cut 50/50 with citrus solvent for the first coat. Let soak in for 15 min, wipe off excess. Cure 24 h. Apply 1–2 more coats of full-strength tung oil. The tapa should *feel* like wood, not plastic.
2. **Body:** apply Arm-R-Seal satin polyurethane in 3 thin coats. Light scuff with 320 grit between coats. Final coat hand-rubbed with steel wool for a satin feel.
3. **Avoid finishing the inside of the cavity** — bare wood absorbs internal reflections more naturally; finished interiors get a glassier high-frequency reflection that some players dislike.

---

## Phase 10 — Feet + final inspection

1. Stick four 1/2″ rubber feet to the bottom panel, one in each corner. Inset 1/2″ from each edge.
2. Final play-test: bass tone (centre), slap (upper corner), tip (mid-edge), brush (drag fingers). Each should produce a distinct voice.
3. Record final cents reading in `validation.csv`. Mark variant + member + tuning instrument used.
4. Photograph per `photo-shotlist.md`.

---

## Compact (CJ-C) and Bass (CJ-B) variants

The Compact and Bass scale by simple geometry. All phases are identical except:

- **Compact:** 15 × 11 × 11; body 0.625″; sound hole 4.0″; tapa 15 × 11 × 0.118″; finger pattern scaled to panel width
- **Bass:** 22 × 14 × 14; body 0.75″; sound hole 5.0″; tapa 22 × 14 × 0.118″; band-clamp count + 2 (use 8–10 for the larger box)

The Bass is heavy — a glued shell is ~25 lb. Two-person glue-up is recommended.

---

## Notes that the workbook does not say

- Tapa screws are slotted-brass for two reasons: visual (they read as old-world hardware), and acoustic (Phillips heads are easier to over-torque, which audibly tightens the bass voice).
- The 4–5″ unscrewed slap zone at the top of the tapa is the *single most important* trad design element. Don't skip it. A fully-screwed tapa sounds dead.
- If the snare buzzes when you strike the centre (not the corner), the snare contact is too tight. Loosen one notch on the tuner peg.
- A new tapa mellows for the first 50–100 hours of play. Do not "fix" it sounding bright on day one.

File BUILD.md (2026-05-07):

# Build instructions — binary deliverables

Three binary files are not checked in directly because they are generated artifacts:

- `Cajon-Family-Design.xlsx` — parametric workbook (alongside the existing `cajon-design-table.xlsx` reference workbook)
- `Cajon-Family-Capstone.pptx` — capstone slide deck
- `Cajon-Family-Print-Packet.pdf` — printable shop packet

The source-of-truth is in the markdown/CSV files. The generator scripts in `scripts/` produce the binaries on demand.

## Run

From the repo root:

```bash
pip install openpyxl python-pptx reportlab
python scripts/build_all.py
```

This produces all three files in the repo root. To regenerate just one, run the corresponding script directly:

```bash
python scripts/build_xlsx.py     # Cajon-Family-Design.xlsx
python scripts/build_pptx.py     # Cajon-Family-Capstone.pptx
python scripts/build_pdf.py      # Cajon-Family-Print-Packet.pdf
```

## Why generated, not committed?

- The xlsx workbook uses real Excel formulas; the canonical state is the formula graph (encoded by the script), not the cached values.
- Regenerating after editing the source CSVs (BOM, sourcing, validation) is a one-command refresh.
- The scripts double as the design table's documentation: anyone reading `build_xlsx.py` can see exactly which formulas drive which cells.

## Editing the design

To change a dimension, formula, or BOM line:

1. Edit the source — `design.md`, `bom.csv`, `sourcing.csv`, `validation.csv`, etc.
2. Run `python scripts/build_all.py` to regenerate the binaries.
3. Commit both the source change and the regenerated binaries.

## Existing reference workbook

`cajon-design-table.xlsx` is the original artisan-style workbook (in-repo). It contains the family table, BOM, build method, and the Wolfram notebook spec. The new generated `Cajon-Family-Design.xlsx` complements it by ingesting the canonical CSVs and providing the corrected Helmholtz formula. The two coexist; the artisan workbook is the human reference, the generated workbook is the data view.

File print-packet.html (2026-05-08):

# Cajon Family Print Packet

Root-mode packet: public-review cajon prototype
First build: CJ-S Standard, V1 finger joint, snare option B
Status: pre-build; measurement fields are pending

## Quick Start

1. Build only the Standard prototype first.
2. Make the square assembly fixture, tapa screw template, and back-panel template before cutting final stock.
3. Mill walnut panels to final thickness and square before joinery.
4. Route any inlay before assembly.
5. Glue the shell square, then mount the tapa with the screw template.
6. Validate tone, buzz, seat load, and finish before calling the packet public-ready.

## Design Summary

The cajon is a six-sided closed box with one thin front plate. The back sound hole creates the Helmholtz cavity response; the tapa creates the plate response; the two couple into the bass voice. The upper tapa corners are intentionally less constrained so the corner strike creates a crisp slap.

Member | Size | Sound hole | Predicted cavity | Predicted plate
CJ-C Compact | 15 x 11 x 11 in | 4.0 in | 107 Hz | 107 Hz
CJ-S Standard | 18 x 12 x 12 in | 4.5 in | 96 Hz | 84 Hz
CJ-B Bass | 22 x 14 x 14 in | 5.0 in | 77 Hz | 60 Hz

## Critical Dimensions

Feature | Dimension | Check
Outer height | 18.000 in | +/-0.020 in
Outer width | 12.000 in | +/-0.020 in
Outer depth | 12.000 in | +/-0.020 in
Body thickness | 0.750 in | +/-0.005 in
Back thickness | 0.500 in | +/-0.005 in
Tapa thickness | 3 mm / 0.118 in | reject inconsistent sheets
Sound hole | 4.500 in diameter | +/-0.020 in
Tapa screws | #6 x 3/4 in brass | 3 in spacing except slap zone

## Build Flow

### Stock, Inlay, and Joinery

Acclimate stock, record actual thickness, route inlay before assembly, and keep decorative cuts away from joint edges. V1 finger joint is the first prototype default; V2, V3, and V4 remain documented variants.

### Shell, Tapa, and Snare

Glue the shell in a square fixture. Cut and deburr the back sound hole. Mount the tapa with the screw template and keep the upper corner slap zones loose. Tension the guitar-string snare so it engages on a medium corner slap.

### Finish

Use tung oil on the tapa and satin finish on the body. Soften seating corners and avoid any finish bridge across the tapa slap-zone gap.

## Validation Sheet

Test | Result | Initials
Panel thickness recorded | ____ | ____
Shell diagonals within 1/16 in | ____ | ____
Seat load 250 lb for 1 hour | ____ | ____
Sound-hole diameter verified | ____ | ____
Tapa screw pattern verified | ____ | ____
Helmholtz frequency recorded | ____ Hz | ____
Plate mode recorded | ____ Hz | ____
Slap spectral delta recorded | ____ dB | ____
Snare onset set to medium strike | ____ | ____
No unintended rattles | ____ | ____

## Public-Release Checklist

- validation.csv contains measured values for CJ-S.
- validation-report.md summarizes the measured outcome.
- Site hero and visual BOM images use actual build photos.
- Supplier prices and lead times have been rechecked.
- The workbook and design.md agree on Helmholtz end correction.
- Public text credits cajon tradition and avoids novelty claims about the cultural form.

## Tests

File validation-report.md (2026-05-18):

# Validation Report

**Status:** pre-build validation plan complete; measured prototype data not yet available.

## Current result

The packet is ready for a human shop review before the first physical build. All acoustic values are predictions from the design table and first-order models. No row in `validation.csv` should be read as measured performance until the `measured_value` and `measurement_date` columns are populated.

The current status is a pre-build V5 build-packet candidate, not a measured or
build-ready release. `visual-output-register.csv` records which artifacts can
support fabrication planning and which remain derived previews or concept
support.

## Prototype under test

| Field | Value |
|---|---|
| Member | CJ-S Standard |
| Variant | V1 finger joint |
| Snare | Option B, guitar-string snare |
| Body | 3/4 in walnut shell |
| Tapa | 3 mm Baltic birch |
| Back | 1/2 in Baltic birch, 4.5 in sound hole |

## Acceptance gates

| Gate | Target | Pass condition | Current state |
|---|---|---|---|
| Shell squareness | Diagonals matched | Each face diagonal pair within 1/16 in | Pending build |
| Seat load | Static load | 250 lb for 1 hour, no joint opening or new rattle | Pending build |
| Sound hole | 4.500 in diameter | +/-0.020 in, clean deburred edge | Pending build |
| Tapa screw pattern | 3 in perimeter spacing with top slap-zone relief | Holes within +/-0.10 in; upper corners left loose | Pending build |
| Helmholtz response | 96 Hz predicted | Measured within +/-15 Hz or model revised | Pending build |
| Plate (1,1) | 84 Hz predicted | Measured within +/-15 percent or model revised | Pending build |
| Coupled bass | 90 Hz predicted | Perceived bass peak documented | Pending build |
| Slap separation | +5 dB at 1 kHz | Corner strike at least +5 dB vs center strike | Pending build |
| Snare onset | Medium strike | No buzz on light tap, clean buzz on medium slap | Pending build |
| Finish feel | Smooth body, natural tapa | No sticky finish, no film bridging slap zone | Pending build |
| Visual authority | Register present | `validate_visual_authority.py` exits 0 | Pass, 16 rows checked |

## Test sequence

1. Inspect panel thickness, flatness, and squareness before cutting joinery.
2. Dry-fit shell in the square assembly jig and record diagonal measurements.
3. Glue shell, cure 24 hours, then repeat diagonal and rocking checks.
4. Mount tapa with the screw template and a diagonal driving pattern.
5. Run the 250 lb seat-load test before snare tensioning.
6. Record center-tap spectrum, corner-slap spectrum, and T60.
7. Tension snare until the onset target is met.
8. Update `validation.csv` and this report with measured values.

## Preliminary risk read

The design has no measured blocker yet. The highest-risk unknowns are tapa material variation, screw torque uniformity, and snare preload. Those are all controllable during build, which makes this a good fast public candidate after a human verifies the joinery plan and physically builds CJ-S.

## Human review checklist

- Confirm the workbook formula for Helmholtz uses `L_eff = t_back + 1.7*r` before presenting the workbook as final.
- Confirm the square assembly jig can clamp the exact outside dimensions without denting finished faces.
- Confirm tuner hardware does not interfere with the player or with the sound-hole airflow.
- Confirm public photos show the real prototype, not placeholder imagery.

## Round 31 V5 Issue Validation

Run before PR:

```bash
jq . capstone-manifest.json
test -f explorer.html
git diff --check
python3 /home/tony/.codex/skills/instrument-maker/scripts/validate_visual_authority.py visual-output-register.csv
```

Observed result: clean. `validate_visual_authority.py` checked 16 rows with no
errors or warnings. `validate_acoustic_law.py family-spec.csv` was also run and
correctly skipped the 3 non-wind rows with no errors or warnings because this
cajon packet is a box-drum / plate-and-Helmholtz system, not a wind or reed
family-spec packet.

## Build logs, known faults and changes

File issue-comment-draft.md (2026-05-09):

# Issue Comment Draft

Draft for `tonykoop/cajon#1` only. Do not post automatically.

Round 1 sprint update:

The local `cajon` repo is already close-ready for human shop review and first-prototype planning. I validated it as the scoped/started second repo for this lane after prioritizing `handpan`.

Current packet shape:

- complete parametric family packet for Compact / Standard / Bass
- Standard CJ-S, V1 finger joint, snare option B identified as the first prototype
- packet docs present: `design.md`, `assembly-manual.md`, BOM, sourcing, cut list, validation, RFQ, visual BOM, drawing brief
- safety/manufacturing coverage is explicit in `risks.md`, `validation-report.md`, `cnc/README.md`, and `jig-decision.md`
- CAD/OpenSCAD starter exists at `cad/cajon-master.scad`
- drawings and jigs are present under `drawings/` and `jigs/`
- build-log site, capstone materials, print packet, and regeneration scripts are present

Validation run:

```bash
python3 /home/tony/.codex/skills/instrument-maker-v4/scripts/validate_packet.py /mnt/c/Users/Tony/Documents/GitHub/cajon --json
python3 /mnt/c/Users/Tony/Documents/GitHub/instrument-maker/skills/v4/instrument-maker-v4/scripts/validate_packet.py /mnt/c/Users/Tony/Documents/GitHub/cajon --json --mode auto
```

Both validators passed with 0 findings.

Remaining assumptions/blockers before closing after human review:

- first physical CJ-S prototype has not been built or measured
- `cajon-design-table.xlsx` needs a final workbook formula review for the Helmholtz end correction before presenting the workbook as final
- real build photos should replace placeholder/public-review visuals before public showcase use
- dust collection, squareness, joinery dry-fit, tapa screw torque, finish masking, seat-load test, and snare onset all remain shop-validation gates

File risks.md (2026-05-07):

# Risks — Cajón Family

Red-team pass over the design. Each risk has a category, severity, mitigation, and an attached verification test that goes into `validation.csv` once the prototype exists.

## Acoustic

### A1 — Helmholtz / plate frequency miss-match produces dead bass
**Severity:** medium
**Description:** The Standard's plate (1,1) is predicted at ~84 Hz and `f_H` at ~96 Hz — close enough to couple but not so close that they fight. If the actual tapa thickness, stiffness, or moisture content shifts the plate by ±20 %, the family table needs adjustment.
**Mitigation:** treat 84 Hz / 96 Hz as predictions, not specifications. Measure both modes on the assembled prototype before declaring tuning. Update `validation.csv` and (if delta > 50 cents) revise the family scaling in the workbook.
**Verification test:** measure plate (1,1) by tapping centre of mounted tapa with a finger and reading the spectrum peak (REW); measure `f_H` by mallet-tapping the box centre with the back hole partially blocked to vary `A`. Both should land within ±10 Hz of prediction.

### A2 — Workbook uses no Helmholtz end-correction
**Severity:** high (already corrected in the v1 design.md but flagged for traceability)
**Description:** The original `cajon-design-table.xlsx` formula `f_H = (c/2π)·√(A/(V·L))` set `L = back-panel-thickness` only. The standard end-correction `1.7·r` for a flush-mounted thin-wall orifice is missing. With `L = 0.5″` and 4.5″ hole on the Standard, the spreadsheet predicts ~282 Hz; with the correct `L_eff = 0.5 + 1.7·(4.5/2) = 4.325″` it predicts ~96 Hz, which matches measured cajón behavior in the literature.
**Mitigation:** workbook formulas should be updated to use `L_eff = t_back + 1.7·(d/2)`; design.md uses the corrected expression. The next workbook revision is queued.
**Verification test:** measure `f_H` directly with REW. Acceptance: within ±15 Hz of the corrected prediction; if measurement matches the *uncorrected* prediction, the physics model is wrong.

### A3 — Tapa orthotropy not modeled
**Severity:** low-medium
**Description:** Baltic-birch ply is mildly orthotropic — fibers in alternating layers. The plate (1,1) prediction uses an isotropic clamped-plate formula and can be off by 10–20 %.
**Mitigation:** treat plate prediction as a coarse first-order estimate. Final tuning is by ear and screw-torque adjustment, not by formula.
**Verification test:** plate (1,1) measured value within ±15 % of prediction is acceptable.

### A4 — Snare buzz onset velocity is unmodeled
**Severity:** medium
**Description:** Whether the snare engages at light, medium, or hard strikes depends on contact pressure between strings and tapa, which is currently dialed by ear with no parameter on the design sheet.
**Mitigation:** record subjective onset velocity on first prototype (1–5 scale) per `validation.csv`; if the engagement feel is wrong, document the tuner-peg tension that fixed it, and consider promoting a "snare contact preload" parameter to the workbook in v2.

## Structural

### S1 — Tapa screw torque non-uniformity creates uneven plate boundary
**Severity:** medium
**Description:** Twenty #6 brass screws around a 12 × 18 perimeter — if torque varies, the plate (1,1) becomes asymmetric, with a different mode at each quadrant. This was *the* surprise of the conga's tunable-rim build, and it applies here too.
**Mitigation:** drive screws by hand, "snug not torqued"; verify with a small torque screwdriver if you have one (target ~3 in-lb each). Diagonal-symmetric driving order — opposite-corner pairs, not edge-by-edge.
**Verification test:** tap each tapa quadrant and read the spectrum peak; cross-check the four quadrant peaks for ±10 cents agreement.

### S2 — Inlay pocket leaves insufficient panel above pocket
**Severity:** low
**Description:** A 0.080″ pocket in 0.625″ Compact side panel leaves 0.545″ of structural panel above the pocket. That's enough for stiffness, but if the inlay is in a high-stress zone (corner joints, screw passes), the residual panel could fail under glue-up clamping.
**Mitigation:** keep inlay zone within the central 70 % of the panel; do **not** route within 1″ of any joint edge.
**Verification test:** measure post-inlay panel deflection at centre with 5 lb point load (dial indicator); reject if deflection > 0.020″.

### S3 — Glue-block pop-out under repeat seat loading
**Severity:** low
**Description:** Internal corner glue blocks add rigidity and shift the plate boundary, but they're glued only — no mechanical fasteners. If glue fails (over time, under repeated player weight cycles), the block could pop free and rattle in the cavity.
**Mitigation:** Titebond III, full-length glue surface (1″ × 1″ × panel-height = ~36 in²). Optional drywall-screw belt-and-suspenders fastening from the outside through the panel into the block (countersink + plug to hide).
**Verification test:** static seat-load test the assembled box at 250 lb (heavier than any expected player) for 1 hour; visual + tap inspection of all 8 internal corners after.

### S4 — Tapa cracking at slap zone over time
**Severity:** medium
**Description:** Repeated bending of the unscrewed top 4–5″ slap-zone over the working life of the cajón fatigues the 3 mm Baltic ply. Eventual delamination is a real failure mode on heavily-played cajons (~1000+ hours).
**Mitigation:** spec only BB-grade or marine-grade ply (consistent layer adhesion); do not over-tighten the lower screws (which would tense the slap zone at rest); if a crack forms, the tapa is field-replaceable since it's only screwed (not glued).
**Verification test:** none on the prototype — this is a long-term failure mode. Note the tapa as a known wear item in the final README.

### S5 — Joint failure under transport
**Severity:** low
**Description:** A 25-lb hollow box is awkward in a car. Drops or impact loads on a corner could split a finger / dovetail / spline joint.
**Mitigation:** all four joinery options spec full-length glue surfaces. Titebond III is rated 4000+ psi shear; well above any plausible impact load on a glued joint area >12 in² per corner. A padded gig-bag for transport is the cheap fix.

## Ergonomic

### E1 — Seat height misfit for short or tall players
**Severity:** medium
**Description:** Standard cajón height of 18″ matches a default 175 cm-ish adult. A 5'4" player lands their thighs near horizontal (good); a 6'4" player lands them angled-down (uncomfortable, hand position too low).
**Mitigation:** publish three sizes (Compact 15″, Standard 18″, Bass 22″) so player-fit can be matched at order time. Note in the README that the Bass is acoustically deepest *and* tallest — there are players who need a Bass for fit, not for tone.
**Verification test:** none — this is documentation-only.

### E2 — Slap-zone hand fatigue
**Severity:** low
**Description:** A poorly-tuned slap zone (over-tight upper screws, or unscrewed margin too short) makes the player hit harder to get the snap, fatiguing fingers and wrists.
**Mitigation:** spec the unscrewed margin at 4–5″ and test the slap stroke for snap with mild effort before declaring the build done. If the player has to hit hard, the build is wrong.

## Supply

### SU1 — Tapa thickness inconsistency from supplier
**Severity:** medium
**Description:** "3 mm" Baltic birch is nominal. Real sheets from non-BB-grade sources can vary ±0.010″, which is ±8 % of the nominal — and plate (1,1) varies as `h³`, so a 10 % thickness change means a ~30 % stiffness change, ~15 % frequency shift.
**Mitigation:** spec BB grade or better and spot-check thickness on arrival. Reject sheets >0.010″ off nominal.
**Verification test:** caliper measurement at 5 points per sheet; record in `validation.csv` per build.

### SU2 — Hard-to-source 3 mm ply (regional availability)
**Severity:** low
**Description:** US suppliers stock 3 mm Baltic birch, but it's a special-order item — not on shelves at big-box stores. International builds may struggle.
**Mitigation:** RFQ document lists Ocooch Hardwoods as US-preferred; alternates: Veneer Supplies, Anderson International. UK/EU builders: search for "3mm birch ply BB grade marine."

### SU3 — Brass screws supplier substitution
**Severity:** low
**Description:** "Brass-plated" steel screws look identical at first glance and are easy to swap in by mistake. Brass plate corrodes; solid brass does not. Also, plated screws magnetically pick up sawdust at the workbench.
**Mitigation:** spec "solid brass" explicitly in `bom.csv` and `sourcing.csv`. Verify with a magnet test on the workbench before installation.

## Fit / finish

### F1 — Inlay press-fit too tight cracks insert
**Severity:** medium
**Description:** Broinwood-style inlay is unforgiving: too-tight fit splits the maple insert when pressed home; too-loose leaves a visible gap line. The inlay-allowance setting in VCarve is the single tuning knob.
**Mitigation:** test cut on scrap before committing. Adjust allowance ±0.005″ until the dry-fit drops in with mild thumb pressure.
**Verification test:** inspect inlay for hairline cracks after press; reject if any cracks visible.

### F2 — Squeeze-out into cavity creates rattle
**Severity:** low
**Description:** Glue squeeze-out from joinery into the cavity — if it dries as a hard bead — can vibrate audibly during play, sounding like a "buzz of unknown origin" that drives the maker mad.
**Mitigation:** wipe squeeze-out with a damp cloth before glue cures; inspect interior with a flashlight after final cure; hand-pick out any beads with a chisel.

### F3 — Finish bleed onto tapa edge
**Severity:** low
**Description:** Arm-R-Seal poly applied to the body can bleed onto the tapa edge at the joint, sealing the slap-zone gap and changing the slap acoustics.
**Mitigation:** mask the tapa's perimeter before finishing the body. Apply tung oil to tapa first (penetrating, no surface film), then mask + finish body.

---

## Risk roll-up

| Category | Highest severity | Open count |
|---|---|---|
| Acoustic | A2 (closed in design.md, flagged for workbook) | 4 |
| Structural | S1, S4 (medium) | 5 |
| Ergonomic | E1 (medium, doc-only) | 2 |
| Supply | SU1 (medium) | 3 |
| Fit/finish | F1 (medium) | 3 |
| **Total** | | **17** |

The single highest-leverage risk on first prototype is **A2 / SU1 in combination** — the workbook's old Helmholtz formula was wrong, *and* tapa thickness can vary in the supply chain. If the build comes in off-pitch, the question to ask first is "what was the actual tapa thickness?" — not "is the design wrong?"

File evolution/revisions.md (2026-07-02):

# Revision Register — cajon

| Rev | Date | Parent | Delta | Downstream artifacts invalidated |
| --- | --- | --- | --- | --- |
| A | 2026-07-01 | — | Stage 0 intake of current masters (cad/cajon-master.scad + Cajon-Family-Design.xlsx + family-spec.csv). | none (no alpha/beta/production artifacts exist yet) |

Stage 0 only. Gate A has not been run; no Alpha compiles, vendor quotes, or production lock exist for this product.

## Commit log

2026-05-02 Initial scaffold: Cajón
    [cajon-design-table.xlsx]
2026-05-07 v4 update
    [Cajon-Family-Design.xlsx, bom.csv, cajon-master.scad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]
2026-05-18 feat(learn-to-play): add cajon starter songbook (#3)
    * feat(learn-to-play): add cajon starter songbook (R4 claude-dan)
    Drop learn-to-play/ with 00-INDEX.md, scales/, fingerings/, and
    5 tunes (ABC + LilyPond + songsheet + notes). All tunes are
    public-domain traditional arrangements or original Heifer Zephyr
    compositions (MIT). Notation is at concert pitch; no external
    rendering tools required to read the ABC files.
    * fix: strip trailing whitespace in learn-to-play songsheets
    ---------
2026-05-18 Add cajon V5 authority register (#6)
    [visual-output-register.csv]
2026-05-29 Blender MCP render scaffolding — provenance log, VOR rows, render brief (Refs #4) (#7)
    - cad/mcp-session-log.md: V5 session log with planned Blender sessions as pending_measurement rows
    - visual-output-register.csv: hero-render, explode, material-study, blender-scene rows added
    - images/render-brief.md: complete camera/lighting/explode/material-study spec for Blender MCP
    - images/material-study/: directory created for planned renders
    - README.md: scaffolding status note added
    Actual renders require Blender MCP via Claude Desktop; all render rows pending_measurement.
    [visual-output-register.csv]
2026-05-31 Add image-gen concept prompt; wire explorer images
2026-06-23 feat(wolfram): deploy interactive model + live explorer embed (#11)
    * feat(v5): upgrade explorer to V5 format + fill build-packet gaps
    - Replace explorer.html with V5 parchment card format: readiness chip,
    authority-split chip, family chip, per-artifact authority badges
    (fabrication / derived_preview / reference_only / source_only)
    - Add data/deliverables-export.json machine-readable manifest
    - Add any missing build-packet stubs (drawing-brief.md, assembly-manual.md,
    supplier-rfq.md, visual-bom-brief.md, photo-shotlist.md, sourcing.csv,
    cut-list.csv, cnc/setup-sheet.md) as TBD-ready placeholders
    Refs instrument-maker v4.5 · tonykoop/cajon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
    [visual-output-register.csv]
2026-07-02 V5 packet refresh: status line, provenance, evolution intake
    - Add normalized README Status line (pre-build V5 candidate -> L2 V5 build-packet
    candidate), keeping the pre-build caveat prose.
    - Provenance: log the three previously-unlogged fabrication artifacts
    (Cajon-Family-Design.xlsx, cajon-design-table.xlsx, data/README.md) plus a
    render-check row for the kept cad/cajon-master.scad (Simple: yes, exit 0).
    - Register cajon-starter.wl (derived_preview / source_only).
    - evolution/ Stage-0 intake (manifest, design-intent, revisions); README File map updated.
    - Kept existing cad/cajon-master.scad (no rewrite).
    v5 validator: 4 failures -> 0 failures.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
    [visual-output-register.csv]
